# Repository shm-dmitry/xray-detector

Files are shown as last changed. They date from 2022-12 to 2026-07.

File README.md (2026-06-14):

V3 version in progress.
V2 version details:

xray-detector, based on SBT-11A sensor, combined with powerbank futures.

At this moment project finished. Everething works, but with several UI-bugs :)

I will fix them in future, but basically project finished.

Features:
- xray-detector on SBT-11A sensor (senses beta & gamma radiation)
- history in sievert, monthly dose, graph with last severall minutes
- beta-radiation rameasurement feature
- flashlight :-)
- powerbank
- long battery life (about half-year) without recharging
- Simple upgrade firmware - Flushing USB port can be accessed with-out unboxing








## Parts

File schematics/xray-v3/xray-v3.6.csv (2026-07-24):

Reference | Qty | Value | DNP | Exclude from BOM | Exclude from Board | Footprint | Datasheet
BT1 | 1 | LiIon, 3.2 ... 4.2V |  |  |  | Connector_Wire:SolderWire-0.75sqmm_1x02_P7mm_D1.25mm_OD3.5mm
C1 | 1 | 10 pF |  |  |  | Capacitor_SMD:C_0603_1608Metric
C2,C28,C42,C44,C46 | 5 | 22 uF |  |  |  | Capacitor_SMD:C_1210_3225Metric
C3,C57,C59,C60 | 4 | 1 uF |  |  |  | Capacitor_SMD:C_0603_1608Metric
C4,C41 | 2 | 100 uF |  |  |  | Capacitor_Tantalum_SMD:CP_EIA-6032-28_Kemet-C_HandSolder
C5,C13,C30,C32 | 4 | 10 uF |  |  |  | Capacitor_SMD:C_0603_1608Metric
C6 | 1 | 1 nF |  |  |  | Capacitor_SMD:C_0603_1608Metric
C7,C8,C9,C11,C18,C20,C21,C22,C24,C29,C34,C36,C39,C45,C47,C48,C49,C51,C52,C53,C54,C55,C56 | 23 | 100 nF |  |  |  | Capacitor_SMD:C_0603_1608Metric
C10 | 1 | 10 nF * |  |  |  | Capacitor_SMD:C_0603_1608Metric
C12 | 1 | ? * |  |  |  | Capacitor_SMD:C_0603_1608Metric
C14 | 1 | 0.47 uF |  |  |  | Capacitor_SMD:C_0603_1608Metric
C15,C16,C17 | 3 | CBB21, 10 nF, 630V |  |  |  | Capacitor_THT:C_Rect_L13.0mm_W6.5mm_P7.50mm_P10.00mm
C19,C25 | 2 | 4.7 uF |  |  |  | Capacitor_SMD:C_0603_1608Metric
C23,C31 | 2 | 470 pF * |  |  |  | Capacitor_SMD:C_0603_1608Metric
C26,C35,C43 | 3 | 2.2 uF |  |  |  | Capacitor_SMD:C_0603_1608Metric
C27,C33 | 2 | CM-120/S, 120pF, 50V, C0G |  |  |  | Capacitor_THT:C_Disc_D5.0mm_W2.5mm_P2.50mm
C37 | 1 | 47 nF |  |  |  | Capacitor_SMD:C_0603_1608Metric
C38 | 1 | 5 nF |  |  |  | Capacitor_SMD:C_0603_1608Metric
C40 | 1 | 33 pF |  |  |  | Capacitor_SMD:C_0603_1608Metric
C50 | 1 | 2 uF |  |  |  | Capacitor_SMD:C_0603_1608Metric
C58,C61 | 2 | 47 uF |  |  |  | Capacitor_Tantalum_SMD:CP_EIA-3528-21_Kemet-B_HandSolder
D1 | 1 | BZV55C3V0 |  |  |  | Diode_SMD:D_MiniMELF
D2,D10 | 2 | SP0503BAHT |  |  |  | Package_TO_SOT_SMD:SOT-143 | http://www.littelfuse.com/~/media/files/littelfuse/technical%20resources/documents/data%20sheets/sp05xxba.pdf
D3 | 1 | 10BQ060 |  |  |  | Diode_SMD:D_SMB_Handsoldering
D4,D5,D6 | 3 | BYV26C |  |  |  | Diode_THT:D_5W_P10.16mm_Horizontal
D7 | 1 | BAT54A |  |  |  | Package_TO_SOT_SMD:SOT-23 | http://www.diodes.com/_files/datasheets/ds11005.pdf
D8 | 1 | BAT54C |  |  |  | Package_TO_SOT_SMD:SOT-23 | http://www.diodes.com/_files/datasheets/ds11005.pdf
D9,D11 | 2 | BAV21W |  |  |  | Diode_SMD:D_SOD-123 | http://www.vishay.com/docs/85543/bav17.pdf
D12 | 1 | L-2060YD |  |  |  | LED_THT:LED_D1.8mm_W3.3mm_H2.4mm
F1 | 1 | 3A |  |  |  | Library:FuseHolder1808
H1,H2,H3,H4,H5 | 5 | MountingHole |  |  |  | MountingHole:MountingHole_2.2mm_M2
J1 | 1 | TR_SHIELD |  |  |  | Connector_Wire:SolderWirePad_1x01_SMD_2x4mm
J2 | 1 | USB_C_Receptacle_USB2.0_16P |  |  |  | Library:USB_C_P16_MIDMOUNT_1.6 | https://www.usb.org/sites/default/files/documents/usb_type-c.zip
J3 | 1 | SBM20_1_+ |  |  |  | Connector_Wire:SolderWirePad_1x01_SMD_2x4mm
J4 | 1 | SBM20_2_+ |  |  |  | Connector_Wire:SolderWirePad_1x01_SMD_2x4mm
J5 | 1 | SBM20_- |  |  |  | Connector_Wire:SolderWirePad_1x01_SMD_2x4mm
J6 | 1 | SBT9_+ |  |  |  | Connector_Wire:SolderWirePad_1x01_SMD_2x4mm
J7 | 1 | SBT9_- |  |  |  | Connector_Wire:SolderWirePad_1x01_SMD_2x4mm
J8 | 1 | USB_A |  |  |  | Library:USB_A | ~
J9 | 1 | DP/VCC |  |  |  | Connector_JST:JST_XH_B3B-XH-A_1x03_P2.50mm_Vertical
J10 | 1 | DSPI |  |  |  | Connector_JST:JST_XH_B4B-XH-A_1x04_P2.50mm_Vertical
J11 | 1 | DP/DC |  |  |  | Connector_JST:JST_XH_B2B-XH-A_1x02_P2.50mm_Vertical
J12 | 1 | Conn_01x06_Pin |  |  | Исключен из платы
L1 | 1 | 1 uH |  |  |  | Inductor_SMD:L_Bourns_SRP1050WA
Q1 | 1 | IRLML0060TR |  |  |  | Package_TO_SOT_SMD:SOT-23 | https://www.infineon.com/dgdl/irlml0030pbf.pdf?fileId=5546d462533600a401535664773825df
Q2,Q3 | 2 | BC847 |  |  |  | Package_TO_SOT_SMD:SOT-23 | http://www.infineon.com/dgdl/Infineon-BC847SERIES_BC848SERIES_BC849SERIES_BC850SERIES-DS-v01_01-en.pdf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
Q4,Q5,Q6,Q7 | 4 | IRLML5203 |  |  |  | Package_TO_SOT_SMD:SOT-23 | https://www.infineon.com/dgdl/irlml5203pbf.pdf?fileId=5546d462533600a40153566868da261d
R1,R2,R3,R7,R8,R12,R13,R19,R38,R47,R49,R50,R51,R55,R56,R57,R58,R60,R63,R66,R70 | 21 | 10K |  |  |  | Resistor_SMD:R_0805_2012Metric_Pad1.20x1.40mm_HandSolder
R4,R46 | 2 | 2K |  |  |  | Resistor_SMD:R_0805_2012Metric_Pad1.20x1.40mm_HandSolder
R5 | 1 | 0.01 |  |  |  | Resistor_SMD:R_2512_6332Metric
R6 | 1 | 5 |  |  |  | Resistor_SMD:R_0805_2012Metric_Pad1.20x1.40mm_HandSolder
R9 | 1 | 1K |  |  |  | Resistor_SMD:R_0805_2012Metric_Pad1.20x1.40mm_HandSolder
R10,R30,R31,R37,R40,R62 | 6 | 200K |  |  |  | Resistor_SMD:R_0805_2012Metric_Pad1.20x1.40mm_HandSolder
R11,R28,R29 | 3 | 5K1 |  |  |  | Resistor_SMD:R_0805_2012Metric_Pad1.20x1.40mm_HandSolder
R14 | 1 | 1M |  |  |  | Resistor_SMD:R_0805_2012Metric_Pad1.20x1.40mm_HandSolder
R15,R16,R33,R44 | 4 | 100K |  |  |  | Resistor_SMD:R_0805_2012Metric_Pad1.20x1.40mm_HandSolder
R17,R18,R21,R22,R24,R25,R26,R27,R34,R35,R36 | 11 | 2M |  |  | Исключен из платы | Resistor_SMD:R_0805_2012Metric_Pad1.20x1.40mm_HandSolder
R20 | 1 | 540 |  |  |  | Resistor_SMD:R_0805_2012Metric_Pad1.20x1.40mm_HandSolder
R23 | 1 | 1K5 |  |  |  | Resistor_SMD:R_0805_2012Metric_Pad1.20x1.40mm_HandSolder
R32,R41 | 2 | 47K |  |  |  | Resistor_SMD:R_0805_2012Metric_Pad1.20x1.40mm_HandSolder
R39,R64 | 2 | 150K |  |  |  | Resistor_SMD:R_0805_2012Metric_Pad1.20x1.40mm_HandSolder
R42 | 1 | 51K |  |  |  | Resistor_SMD:R_0805_2012Metric_Pad1.20x1.40mm_HandSolder
R43 | 1 | 16K |  |  |  | Resistor_SMD:R_0805_2012Metric_Pad1.20x1.40mm_HandSolder
R45 | 1 | 17.5K |  |  |  | Resistor_SMD:R_0805_2012Metric_Pad1.20x1.40mm_HandSolder
R48 | 1 | 0R025 |  |  |  | Resistor_SMD:R_2512_6332Metric
R52,R53 | 2 | 4K7 |  |  |  | Resistor_SMD:R_0805_2012Metric_Pad1.20x1.40mm_HandSolder
R54 | 1 | 0 |  |  |  | Resistor_SMD:R_0805_2012Metric_Pad1.20x1.40mm_HandSolder
R59 | 1 | 500 |  |  |  | Resistor_SMD:R_0805_2012Metric_Pad1.20x1.40mm_HandSolder
R61 | 1 | 20K |  |  |  | Resistor_SMD:R_0805_2012Metric_Pad1.20x1.40mm_HandSolder
R65 | 1 | 20 |  |  |  | Resistor_SMD:R_0805_2012Metric_Pad1.20x1.40mm_HandSolder
R67,R68,R69 | 3 | 0 * |  |  |  | Resistor_SMD:R_0805_2012Metric_Pad1.20x1.40mm_HandSolder
R71 | 1 | 620 |  |  |  | Resistor_SMD:R_0805_2012Metric_Pad1.20x1.40mm_HandSolder
RV1 | 1 | JBR-3296W-103-R |  |  |  | Potentiometer_THT:Potentiometer_Bourns_3296W_Vertical
SW1 | 1 | SW_SP3T_SH |  |  |  | Library:SK13D07VG4
SW2 | 1 | START |  |  |  | Library:SW_Tactile_SKHH_Angled_SH | https://www.ckswitches.com/media/1482/kms.pdf
SW3 | 1 | RESET |  |  |  | Button_Switch_THT:SW_TH_Tactile_Omron_B3F-107x
TH1 | 1 | NTC, 10K |  |  |  | Connector_Wire:SolderWire-0.25sqmm_1x02_P4.2mm_D0.65mm_OD1.7mm
TP1 | 1 | BS_WKUP |  |  |  | TestPoint:TestPoint_Loop_D2.50mm_Drill1.0mm
TP2 | 1 | BS_INT |  |  |  | TestPoint:TestPoint_Loop_D2.50mm_Drill1.0mm
TP3 | 1 | UV_DISCH |  |  |  | TestPoint:TestPoint_2Pads_Pitch5.08mm_Drill1.3mm
TP4 | 1 | VCCQ |  |  |  | TestPoint:TestPoint_Pad_1.0x1.0mm
TP5 | 1 | SBM20_SGN |  |  |  | TestPoint:TestPoint_Pad_1.0x1.0mm
TP6 | 1 | SBT9_SGN |  |  |  | TestPoint:TestPoint_Pad_1.0x1.0mm
TP7 | 1 | B_WKUP |  |  |  | TestPoint:TestPoint_Pad_1.0x1.0mm
TP8 | 1 | RST_DIV |  |  |  | TestPoint:TestPoint_Pad_1.0x1.0mm
TP9 | 1 | HV_PWM |  |  |  | TestPoint:TestPoint_Loop_D2.50mm_Drill1.0mm
TP10 | 1 | HV_FB |  |  |  | TestPoint:TestPoint_Loop_D2.50mm_Drill1.0mm
TP11 | 1 | TIMER_ON_IMPL |  |  |  | TestPoint:TestPoint_Pad_1.0x1.0mm
TP12 | 1 | RST_CHK |  |  |  | TestPoint:TestPoint_Pad_1.0x1.0mm
TP13 | 1 | RST_ON |  |  |  | TestPoint:TestPoint_Pad_1.0x1.0mm
TP14 | 1 | SBM20_SGN_MK |  |  |  | TestPoint:TestPoint_Loop_D2.50mm_Drill1.0mm
TP15 | 1 | SBT9_SGM_MK |  |  |  | TestPoint:TestPoint_Loop_D2.50mm_Drill1.0mm
TP16 | 1 | RST_SGN |  |  |  | TestPoint:TestPoint_Pad_1.0x1.0mm
TP17 | 1 | GND |  |  |  | TestPoint:TestPoint_THTPad_3.0x3.0mm_Drill1.5mm
TP18 | 1 | MK_WKUP |  |  |  | TestPoint:TestPoint_Pad_1.0x1.0mm
TP19 | 1 | MK_ALARM |  |  |  | TestPoint:TestPoint_Pad_1.0x1.0mm
TP20 | 1 | UART_EN |  |  |  | TestPoint:TestPoint_Pad_1.0x1.0mm
TR1 | 1 |  |  |  |  | Library:transformator_SMD_MICRO_EE0504S | https://ae01.alicdn.com/kf/S0bdd4a446f3545a196faa6f50671a665X.jpg
U1 | 1 | BQ27441DRZR-G1A |  |  |  | Library:Texas_S-PDSO-N12_novia | http://www.ti.com/lit/ds/symlink/bq27441-g1.pdf
U2 | 1 | CP2102N-Axx-xQFN28 |  |  |  | Package_DFN_QFN:QFN-28-1EP_5x5mm_P0.5mm_EP3.35x3.35mm | https://www.silabs.com/documents/public/data-sheets/cp2102n-datasheet.pdf
U3,U4,U5,U8,U9,U10 | 6 | SN74LVC1G126DBVR |  |  |  | Package_TO_SOT_SMD:SOT-23-5 | https://www.ti.com/lit/ds/symlink/sn74lvc1g125.pdf
U6,U7,U22 | 3 | SN74LVC1T45DCK |  |  |  | Package_TO_SOT_SMD:SOT-363_SC-70-6 | http://www.ti.com/lit/ds/symlink/sn74lvc1t45.pdf
U11,U13 | 2 | TPS22965 |  |  |  | Package_SON:WSON-8-1EP_3x2.5mm_P0.5mm_EP1.2x1.5mm_PullBack | https://static.chipdip.ru/lib/486/DOC014486558.pdf
U12 | 1 | BQ24090DGQ |  |  |  | Package_SO:MSOP-10-1EP_3x3mm_P0.5mm_EP1.73x1.98mm | http://www.ti.com/lit/ds/symlink/bq24090.pdf
U14 | 1 | TPS61088 |  |  |  | Library:VQFN_20 | https://static.chipdip.ru/lib2/b/858/DOC080858365.pdf
U15,U16 | 2 | ATtiny1616-M |  |  |  | Package_DFN_QFN:VQFN-20-1EP_3x3mm_P0.4mm_EP1.7x1.7mm | http://ww1.microchip.com/downloads/en/DeviceDoc/ATtiny3216_ATtiny1616-data-sheet-40001997B.pdf
U17 | 1 | INA199A3 |  |  |  | Package_TO_SOT_SMD:SOT-363_SC-70-6 | http://www.ti.com/lit/ds/symlink/ina199.pdf
U18,U20 | 2 | LMV331 |  |  |  | Package_TO_SOT_SMD:SOT-23-5_HandSoldering | http://www.ti.com/lit/ds/symlink/lmv331.pdf
U19 | 1 | RV-3028-C7 |  |  |  | Package_SON:MicroCrystal_C7_SON-8_1.5x3.2mm_P0.9mm | https://www.microcrystal.com/fileadmin/Media/Products/RTC/Datasheet/RV-3028-C7.pdf
U21 | 1 | SN74LVC2T45DCUR |  |  |  | Package_SO:VSSOP-8_2.3x2mm_P0.5mm | http://www.ti.com/lit/ds/symlink/sn74lvc2t45.pdf
U23 | 1 | XC6206P282MR |  |  |  | Package_TO_SOT_SMD:SOT-23-3 | https://www.torexsemi.com/file/xc6206/XC6206.pdf
U24 | 1 | Display_2.2inch_ili9341 |  |  | Исключен из платы | Connector_JST:JST_XH_B9B-XH-A_1x09_P2.50mm_Vertical
V1,V2 | 2 | СБМ-20 |  |  | Исключен из платы | Connector_Wire:SolderWire-0.5sqmm_1x02_P4.8mm_D0.9mm_OD2.3mm
V3 | 1 | СБТ-9 |  |  | Исключен из платы | Connector_Wire:SolderWire-0.5sqmm_1x02_P4.8mm_D0.9mm_OD2.3mm

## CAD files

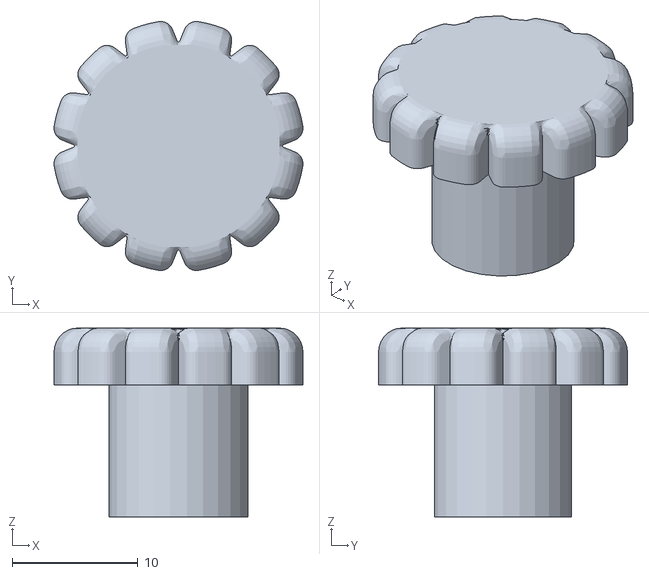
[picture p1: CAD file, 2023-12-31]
3d/box-v2-encoder-cup.stl
19.8 x 19.8 x 15.0

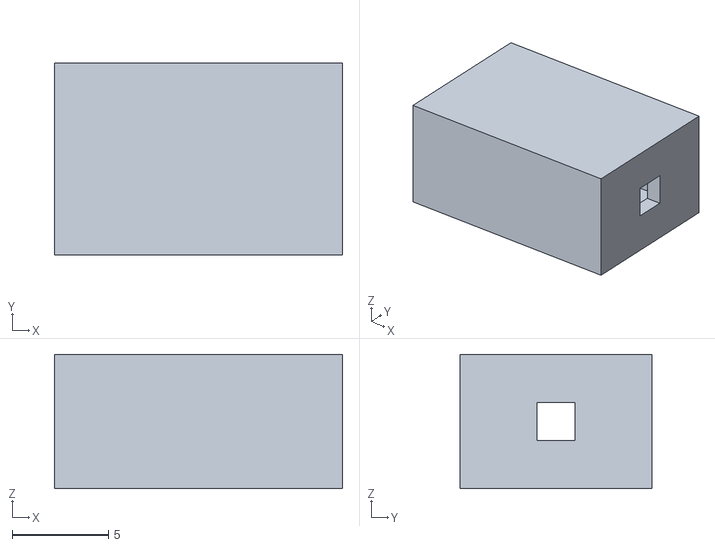
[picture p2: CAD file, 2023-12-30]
3d/box-v2-diode-heat-protection.stl
15.0 x 10.0 x 7.00

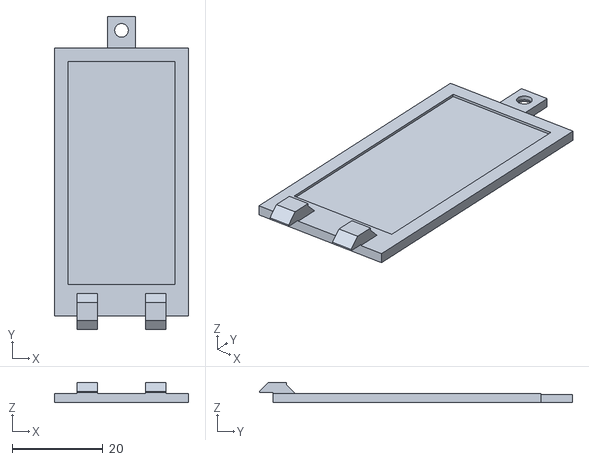
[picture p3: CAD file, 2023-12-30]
3d/box-v2-rad-cap.stl
29.6 x 69.2 x 4.50

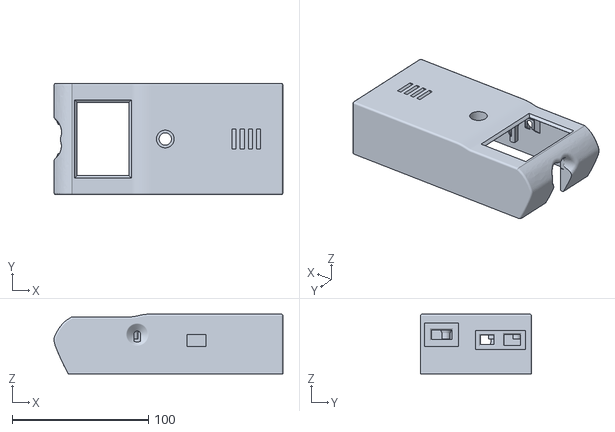
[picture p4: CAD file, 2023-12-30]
3d/box-v2-top.stl
168.1 x 81.8 x 44.0

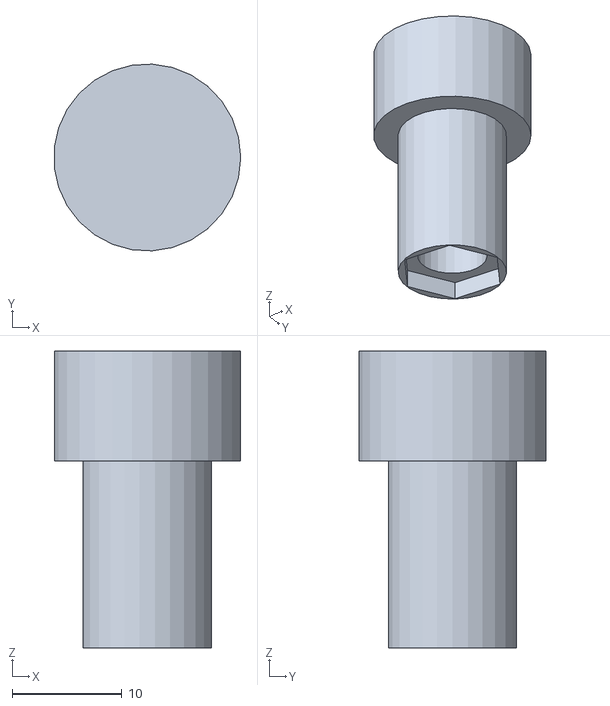
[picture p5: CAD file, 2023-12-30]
3d/box-v2-key.stl
17.0 x 17.0 x 27.0

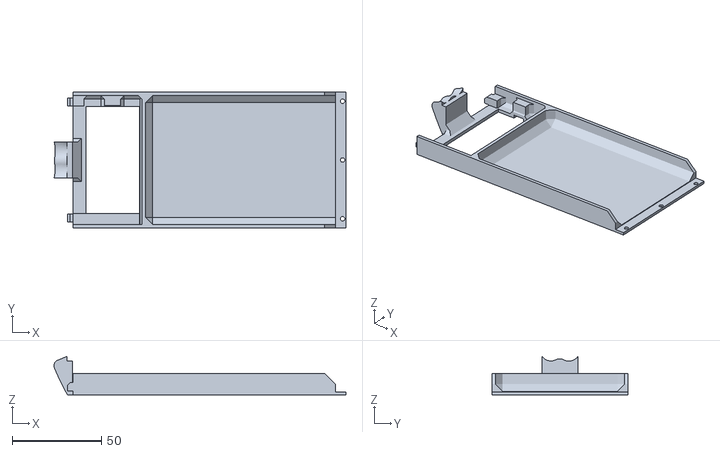
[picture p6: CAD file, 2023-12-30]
3d/box-v2-cup.stl
163.5 x 76.2 x 21.7

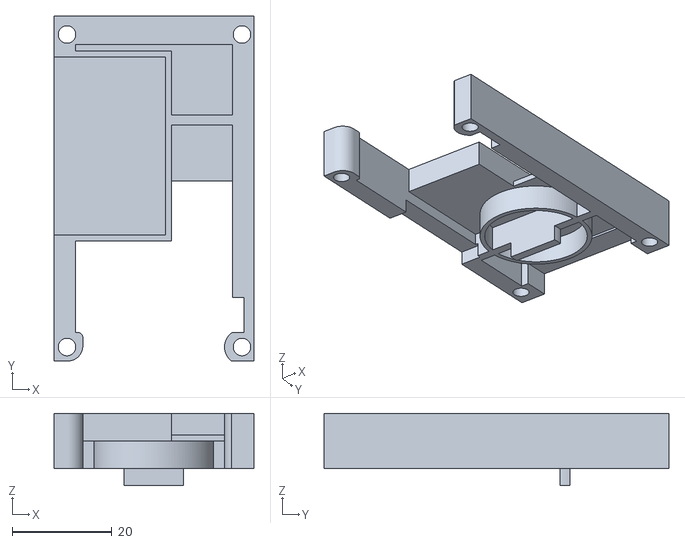
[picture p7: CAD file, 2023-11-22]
3d/box-v2-display-holder.stl
40.0 x 69.0 x 14.5

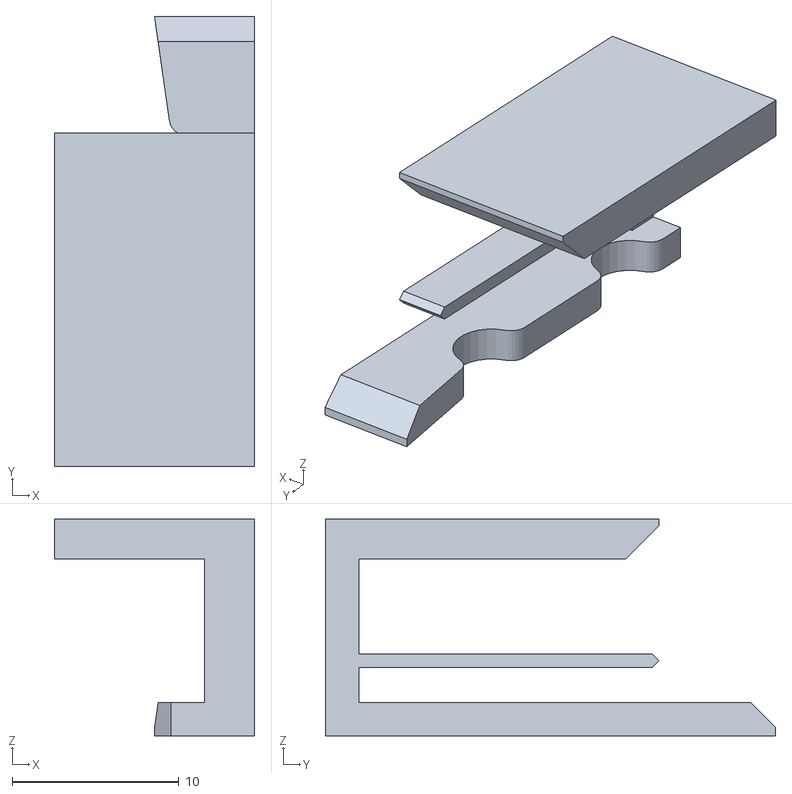
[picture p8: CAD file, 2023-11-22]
3d/box-v2-usb-solder-helper.stl
12.0 x 27.0 x 13.0

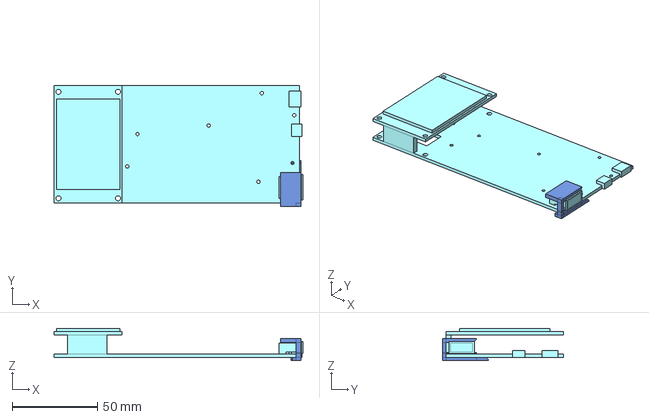
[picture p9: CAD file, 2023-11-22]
3d/box-v2.FCStd
146.2 x 71.0 x 19.0 mm
board
usb-solder-helper

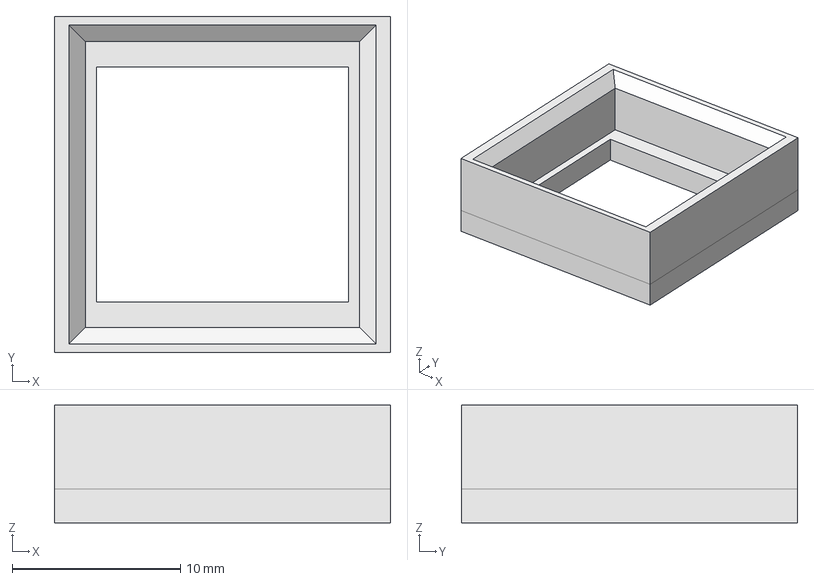
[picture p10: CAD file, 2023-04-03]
3d/transformator-box.FCStd
20.0 x 20.0 x 7.00 mm

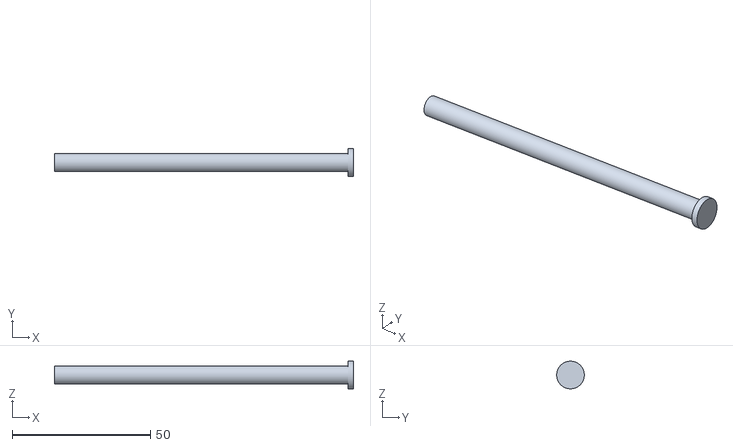
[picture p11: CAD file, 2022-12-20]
3d/transformator-winding-machine-shaft.stl
108.0 x 10.0 x 10.00

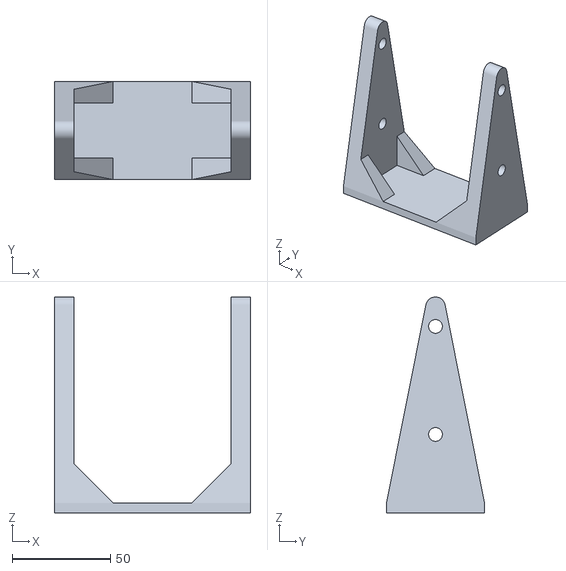
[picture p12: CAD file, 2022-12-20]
3d/transformator-winding-machine-platform.stl
100.0 x 50.0 x 110.0

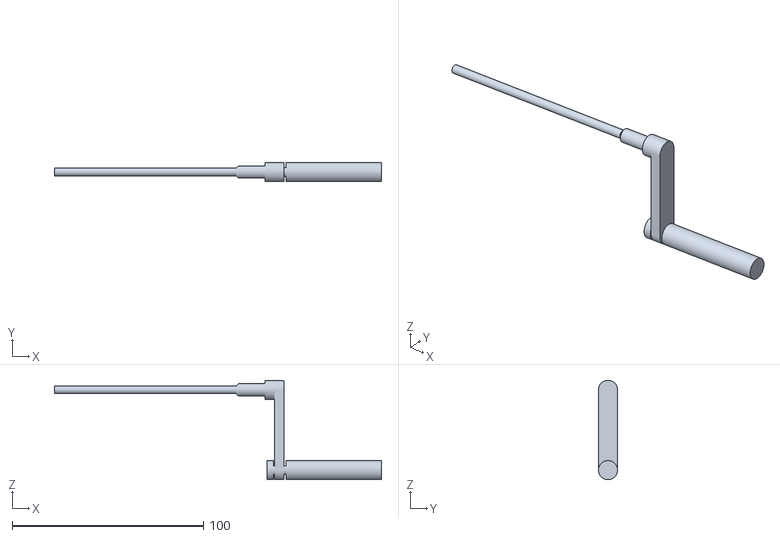
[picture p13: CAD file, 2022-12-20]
3d/transformator-winding-machine-hand.stl
171.0 x 10.0 x 52.0

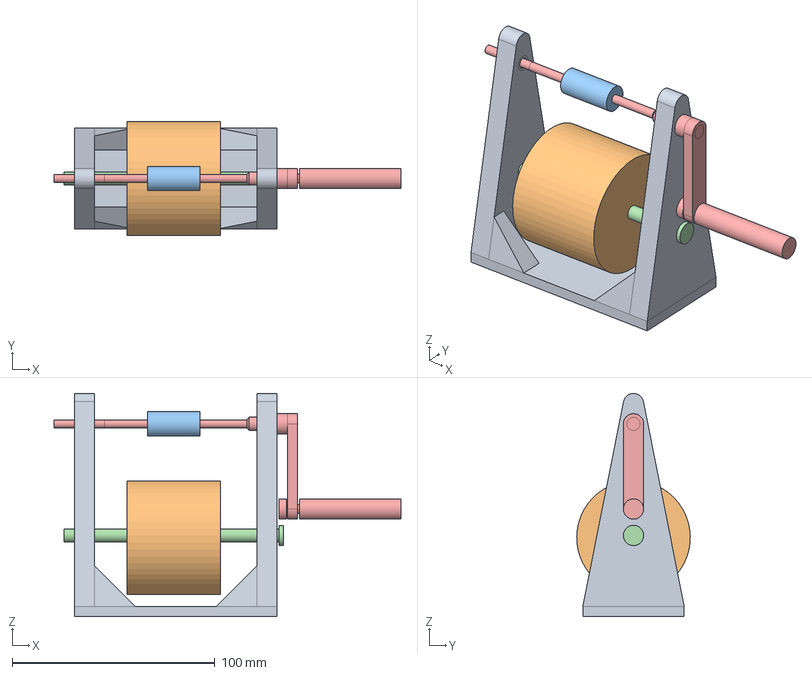
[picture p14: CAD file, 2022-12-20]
3d/transformator-winding-machine.FCStd
171.0 x 56.0 x 110.0 mm
platform
Цилиндр
Цилиндр001
shaft
hand

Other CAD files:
3d/transformator-box.stl

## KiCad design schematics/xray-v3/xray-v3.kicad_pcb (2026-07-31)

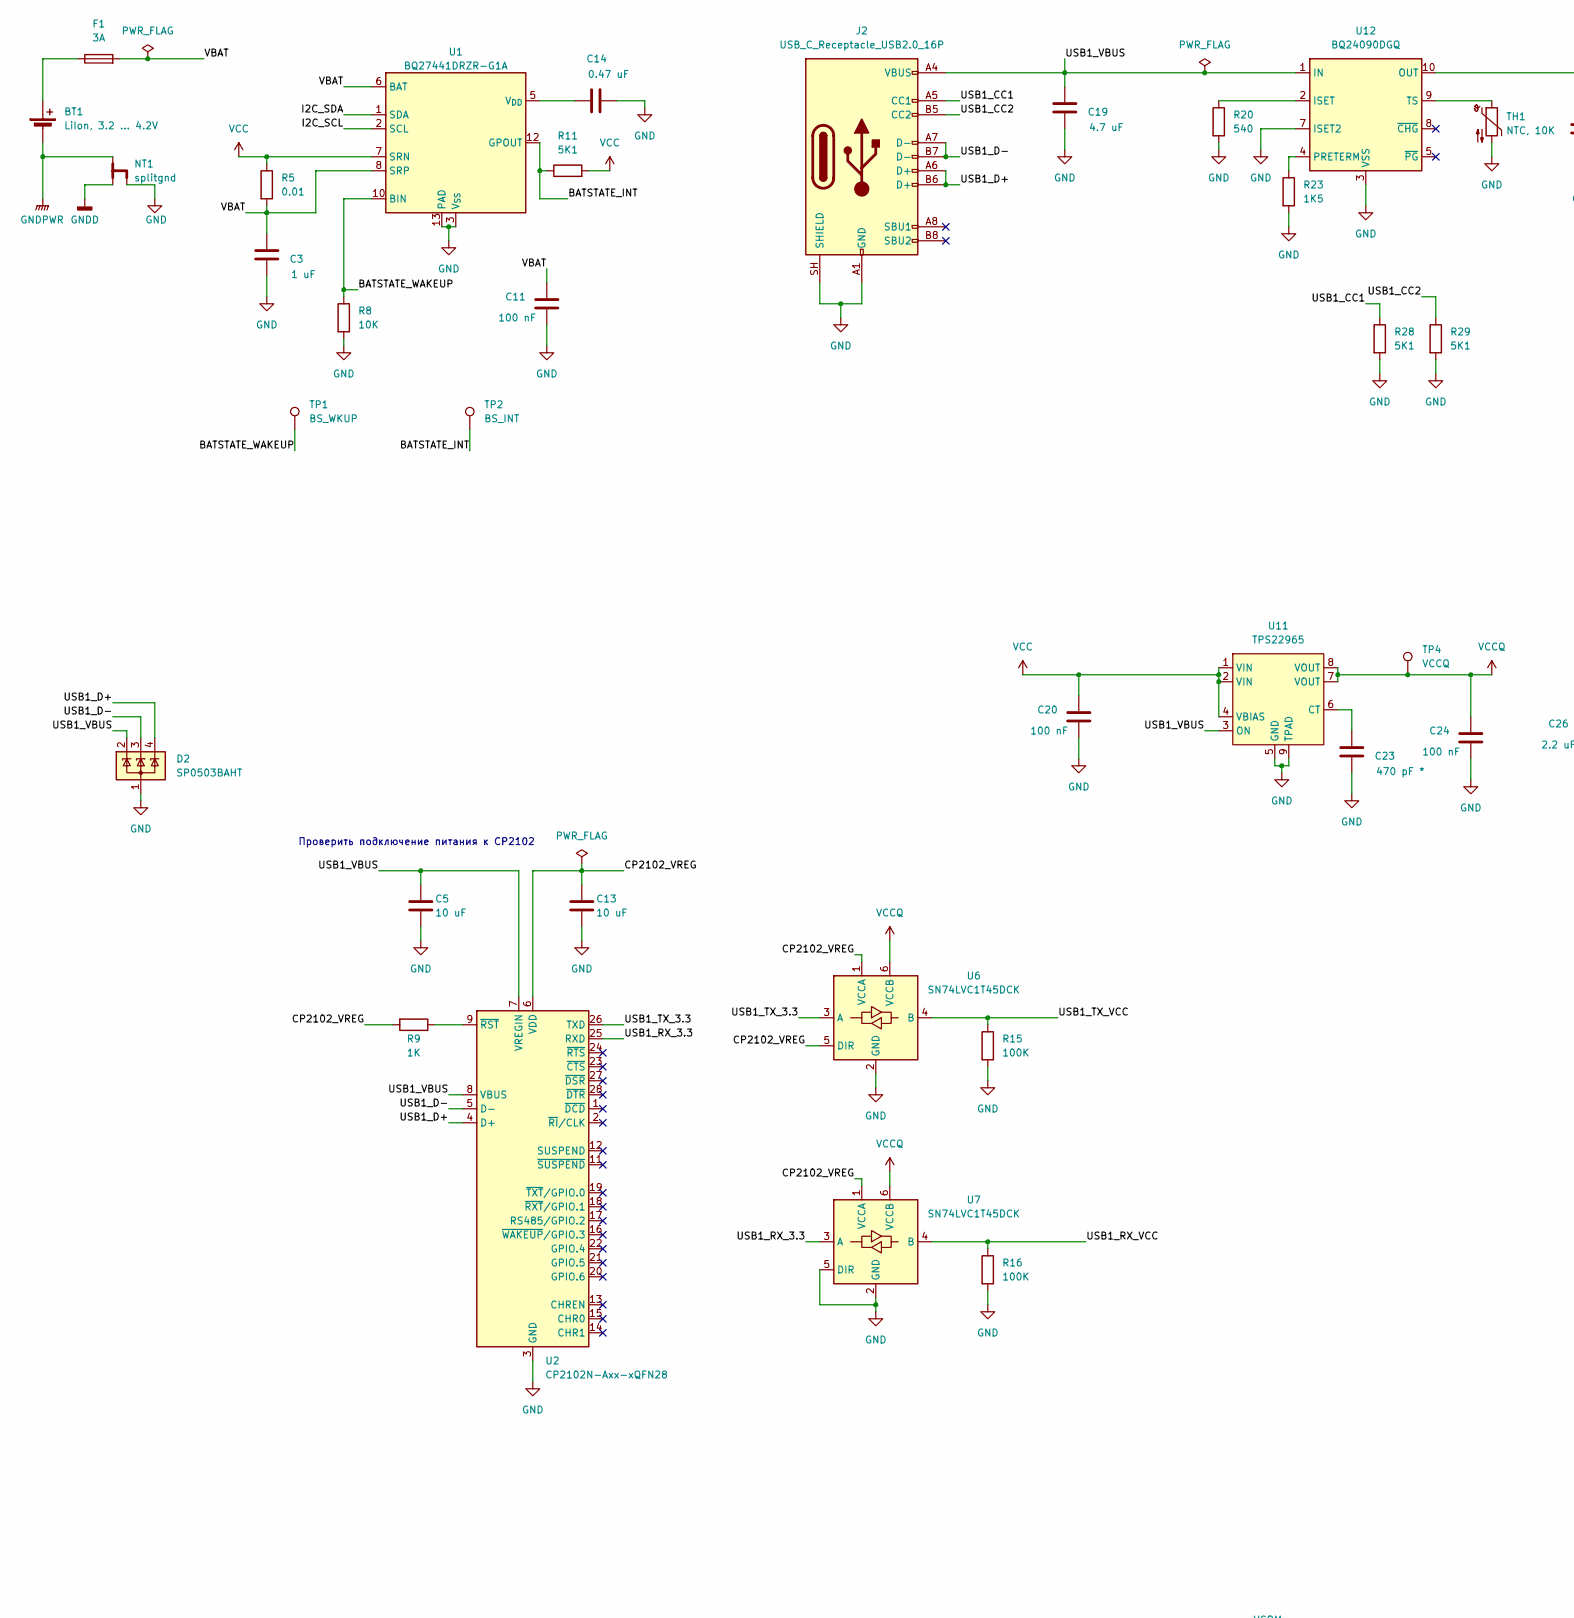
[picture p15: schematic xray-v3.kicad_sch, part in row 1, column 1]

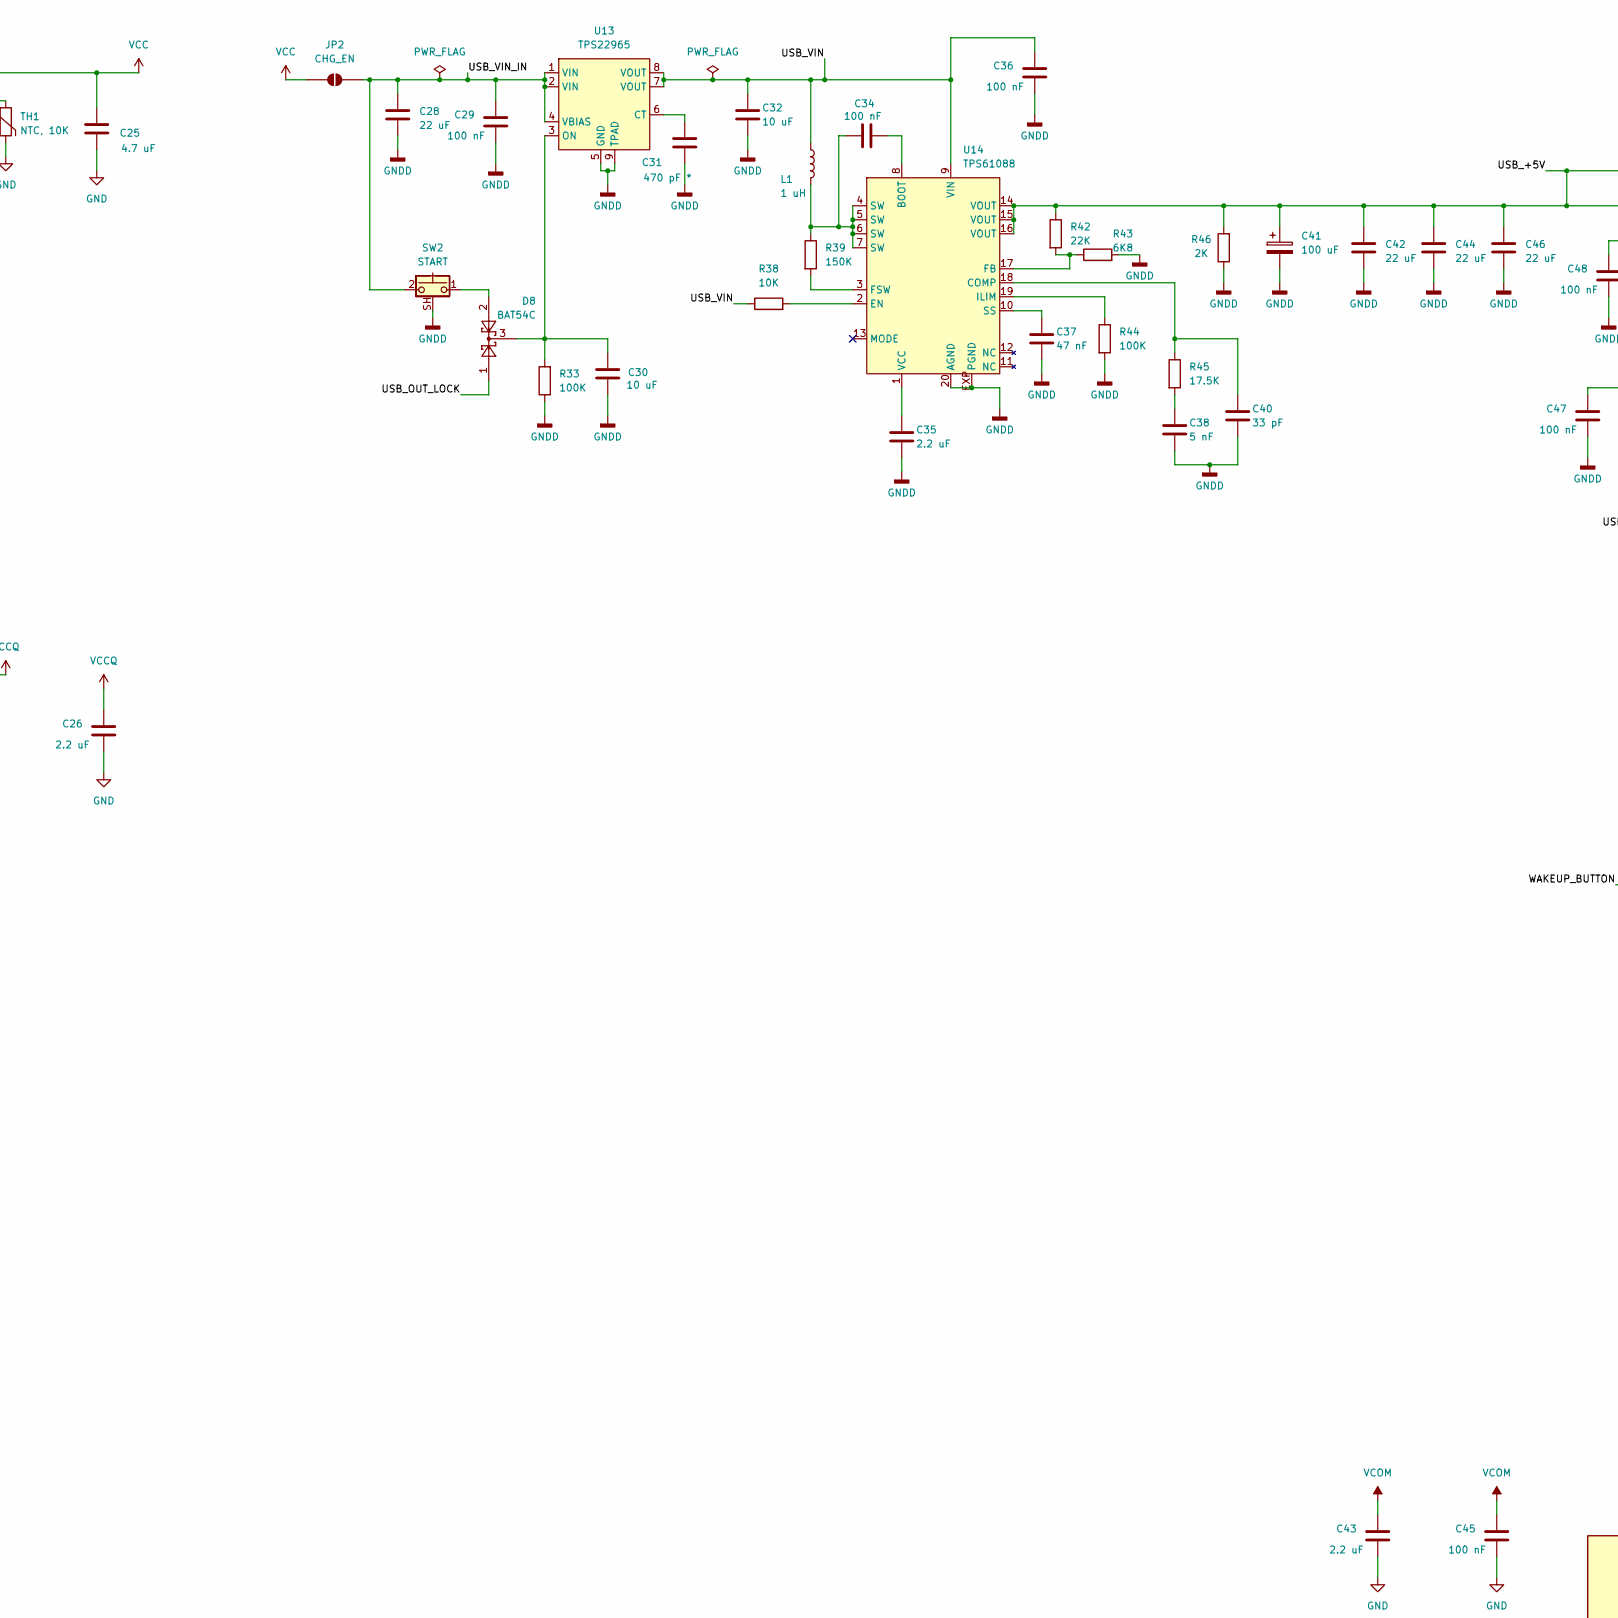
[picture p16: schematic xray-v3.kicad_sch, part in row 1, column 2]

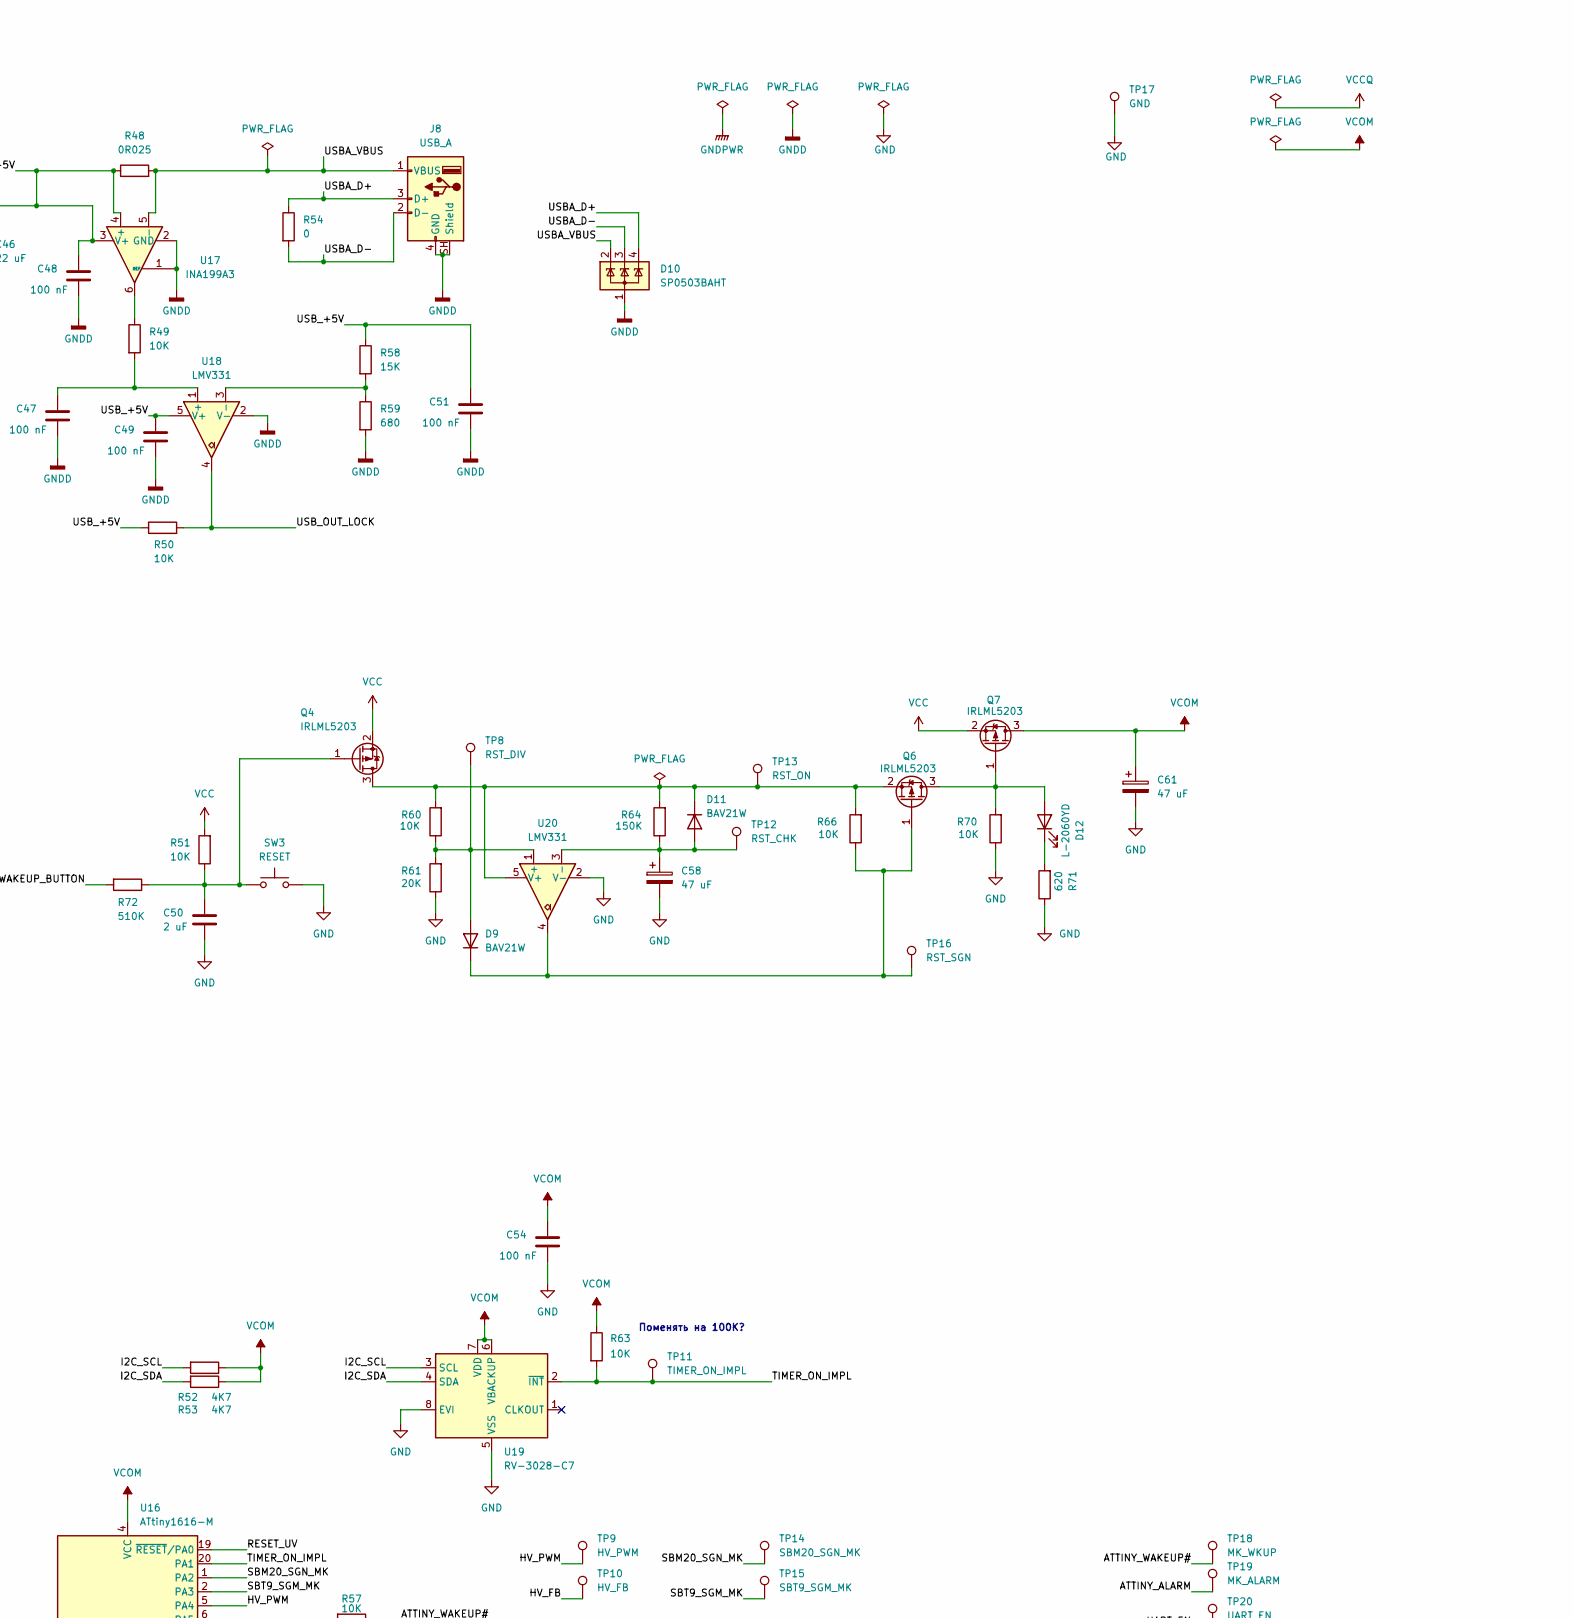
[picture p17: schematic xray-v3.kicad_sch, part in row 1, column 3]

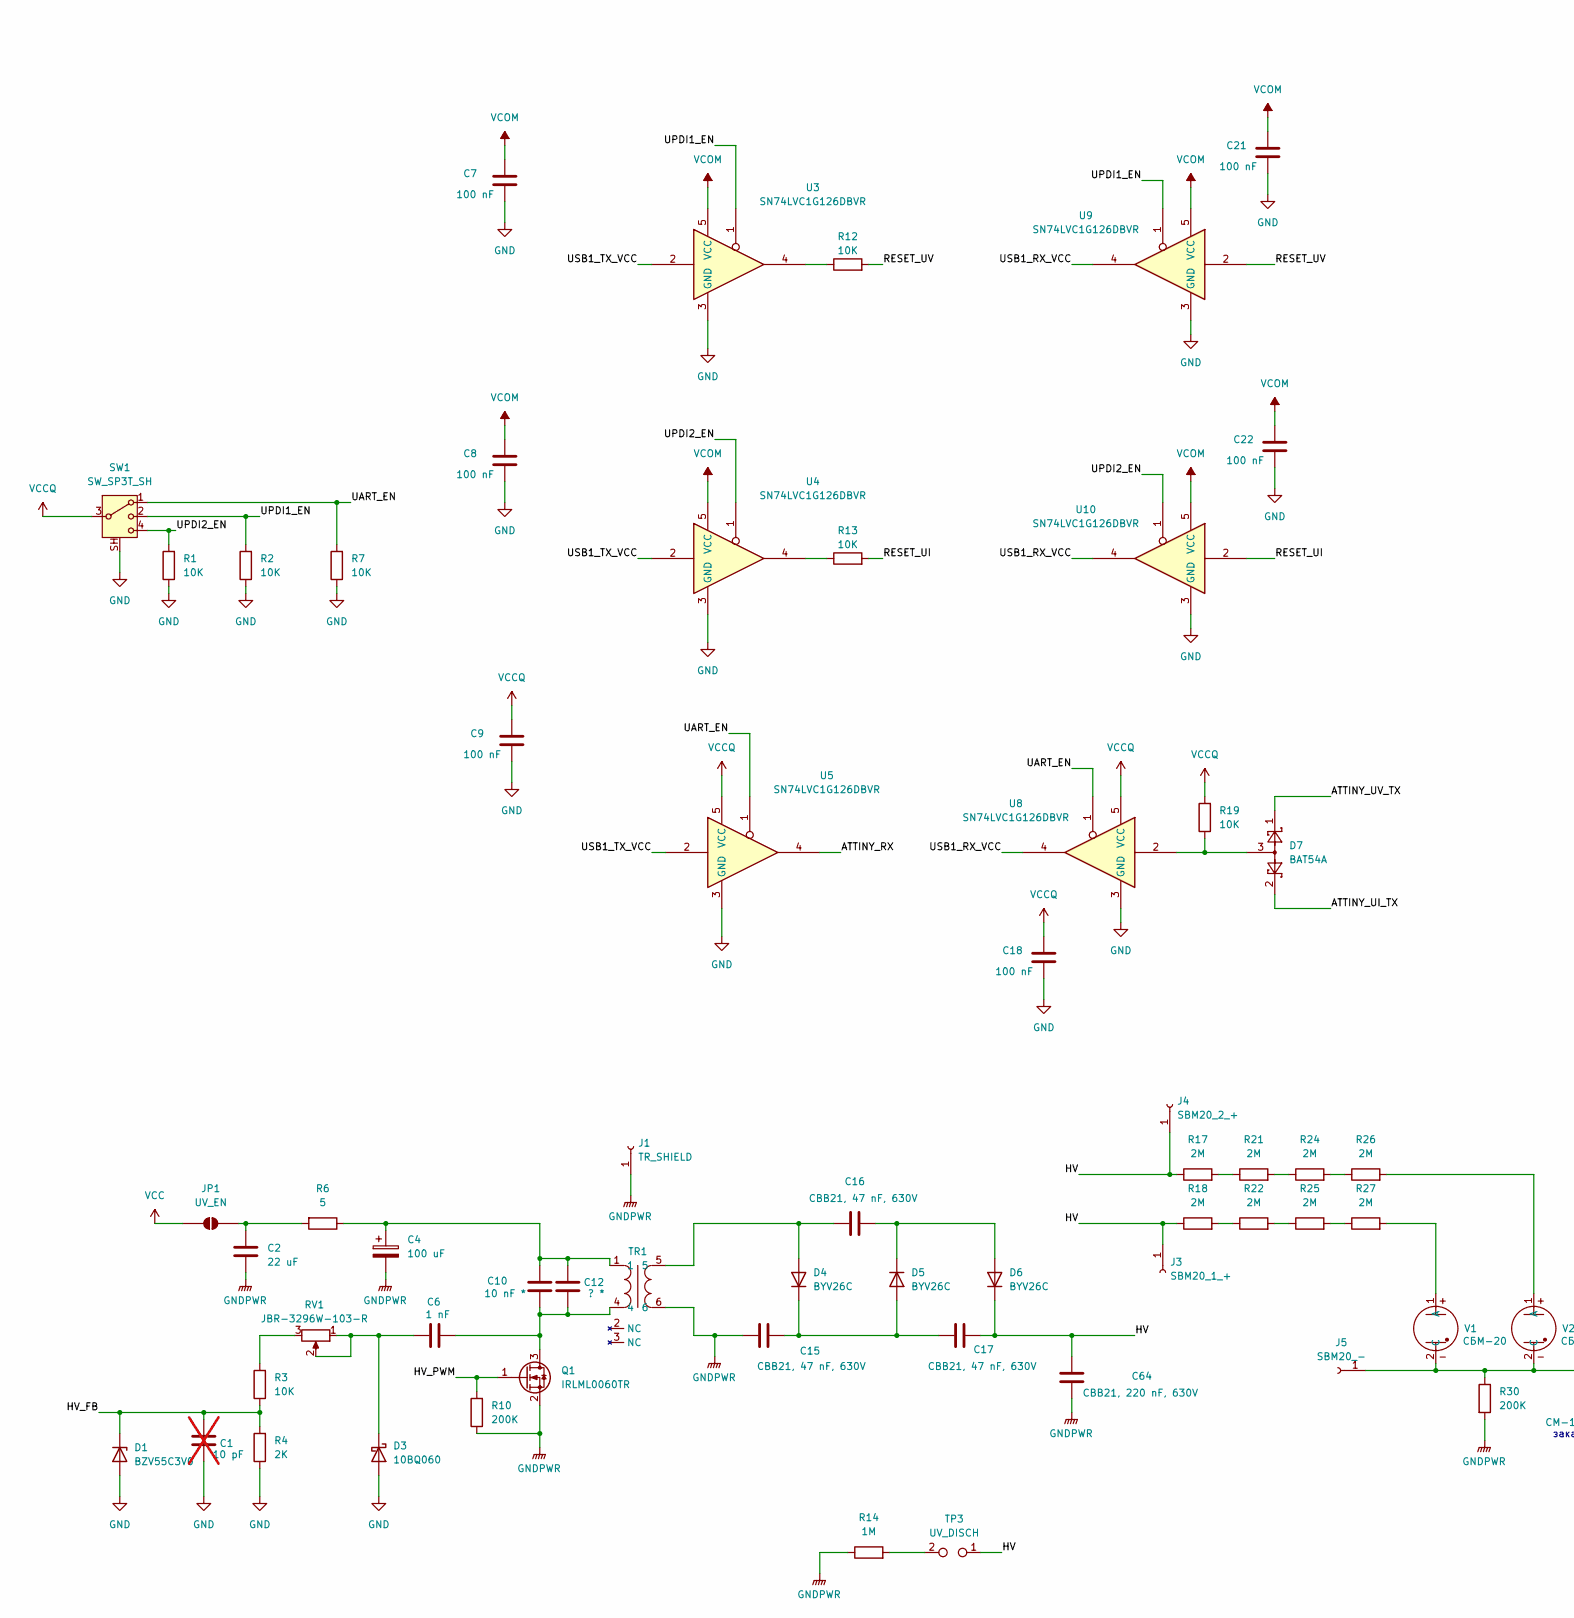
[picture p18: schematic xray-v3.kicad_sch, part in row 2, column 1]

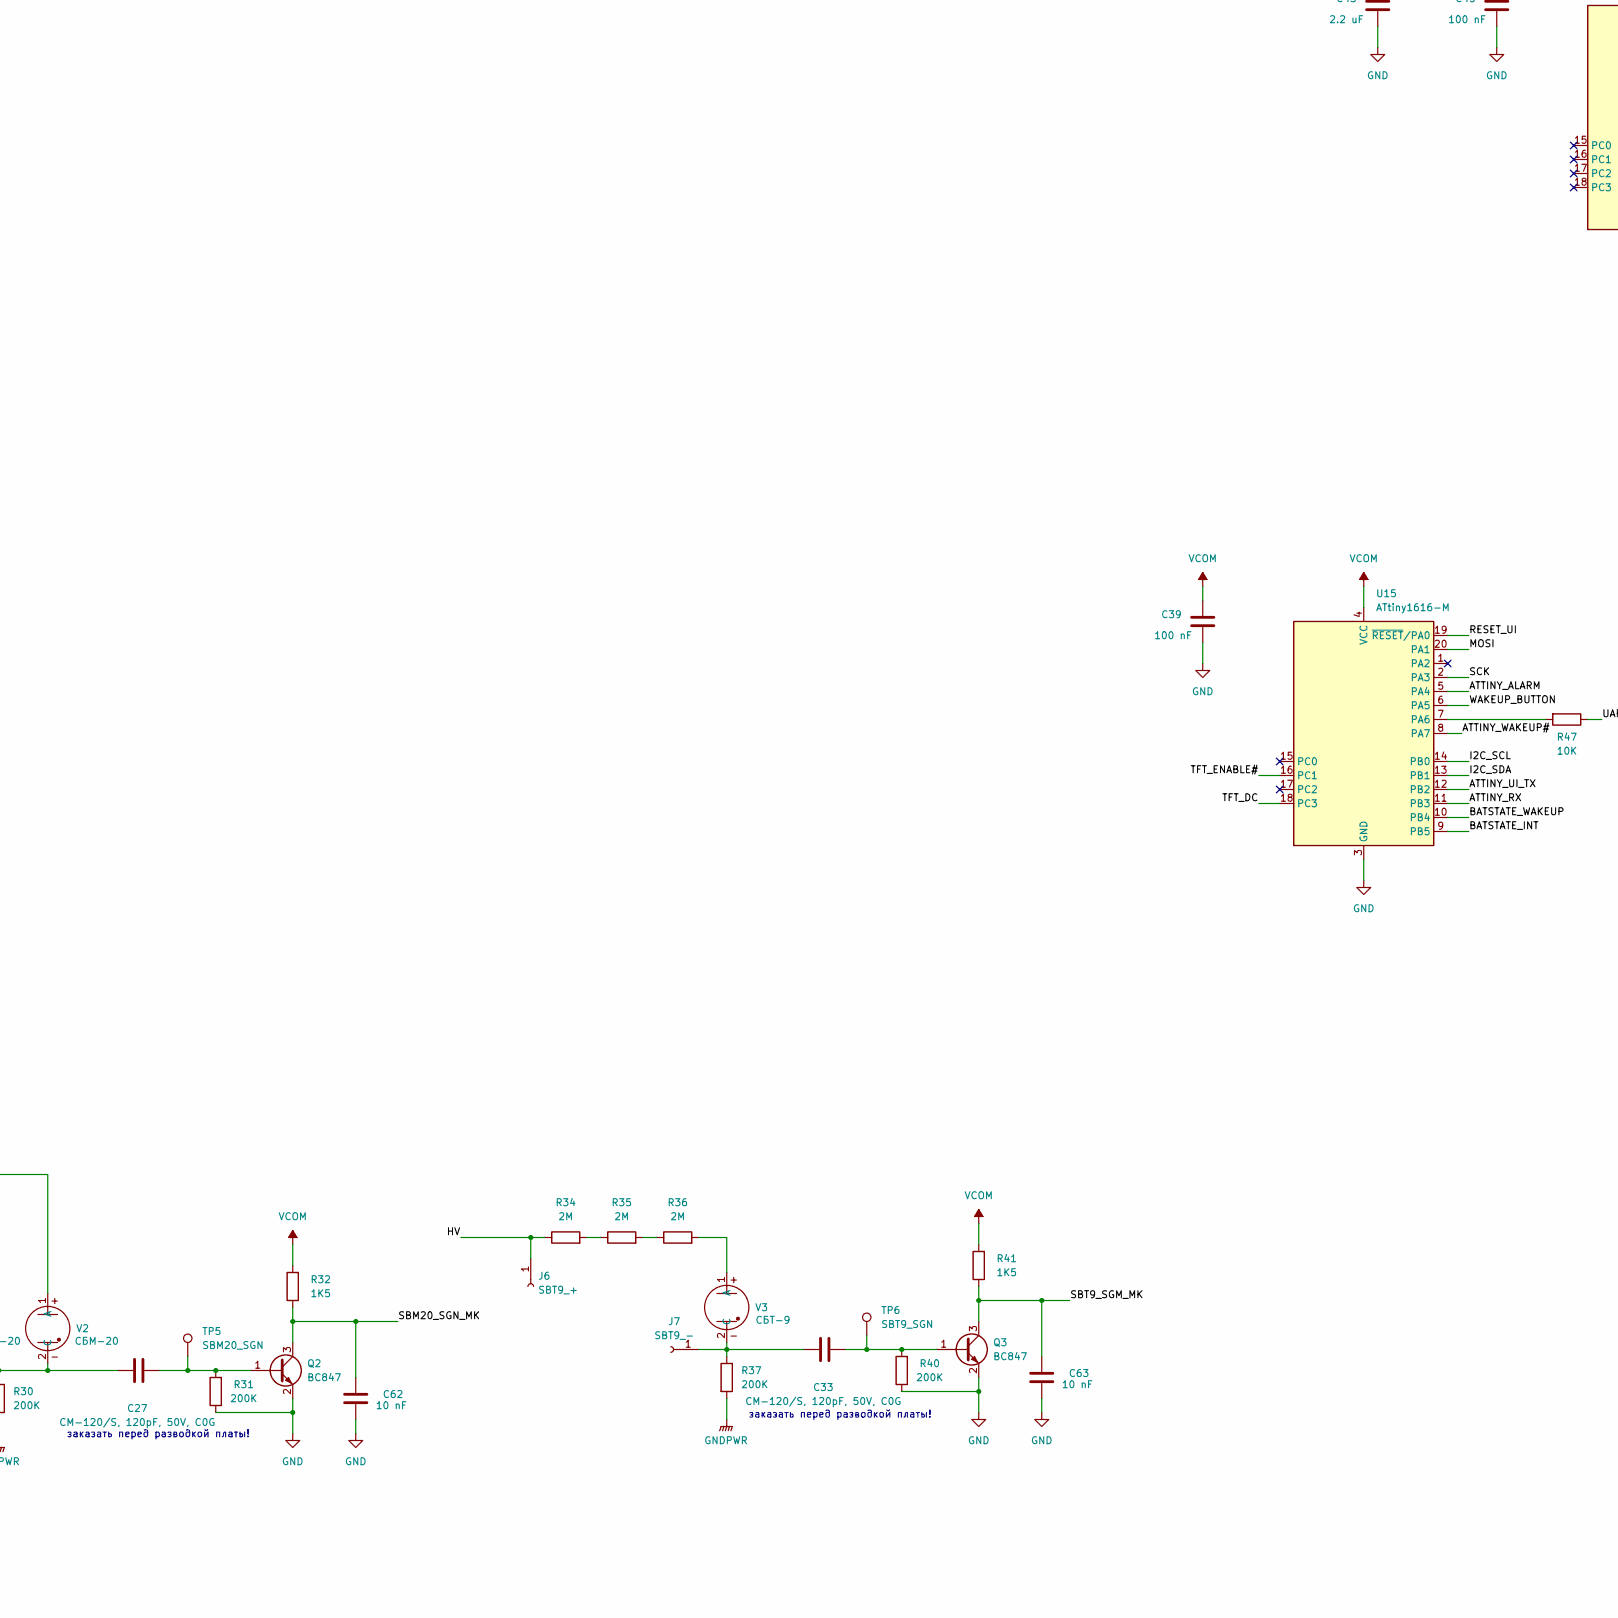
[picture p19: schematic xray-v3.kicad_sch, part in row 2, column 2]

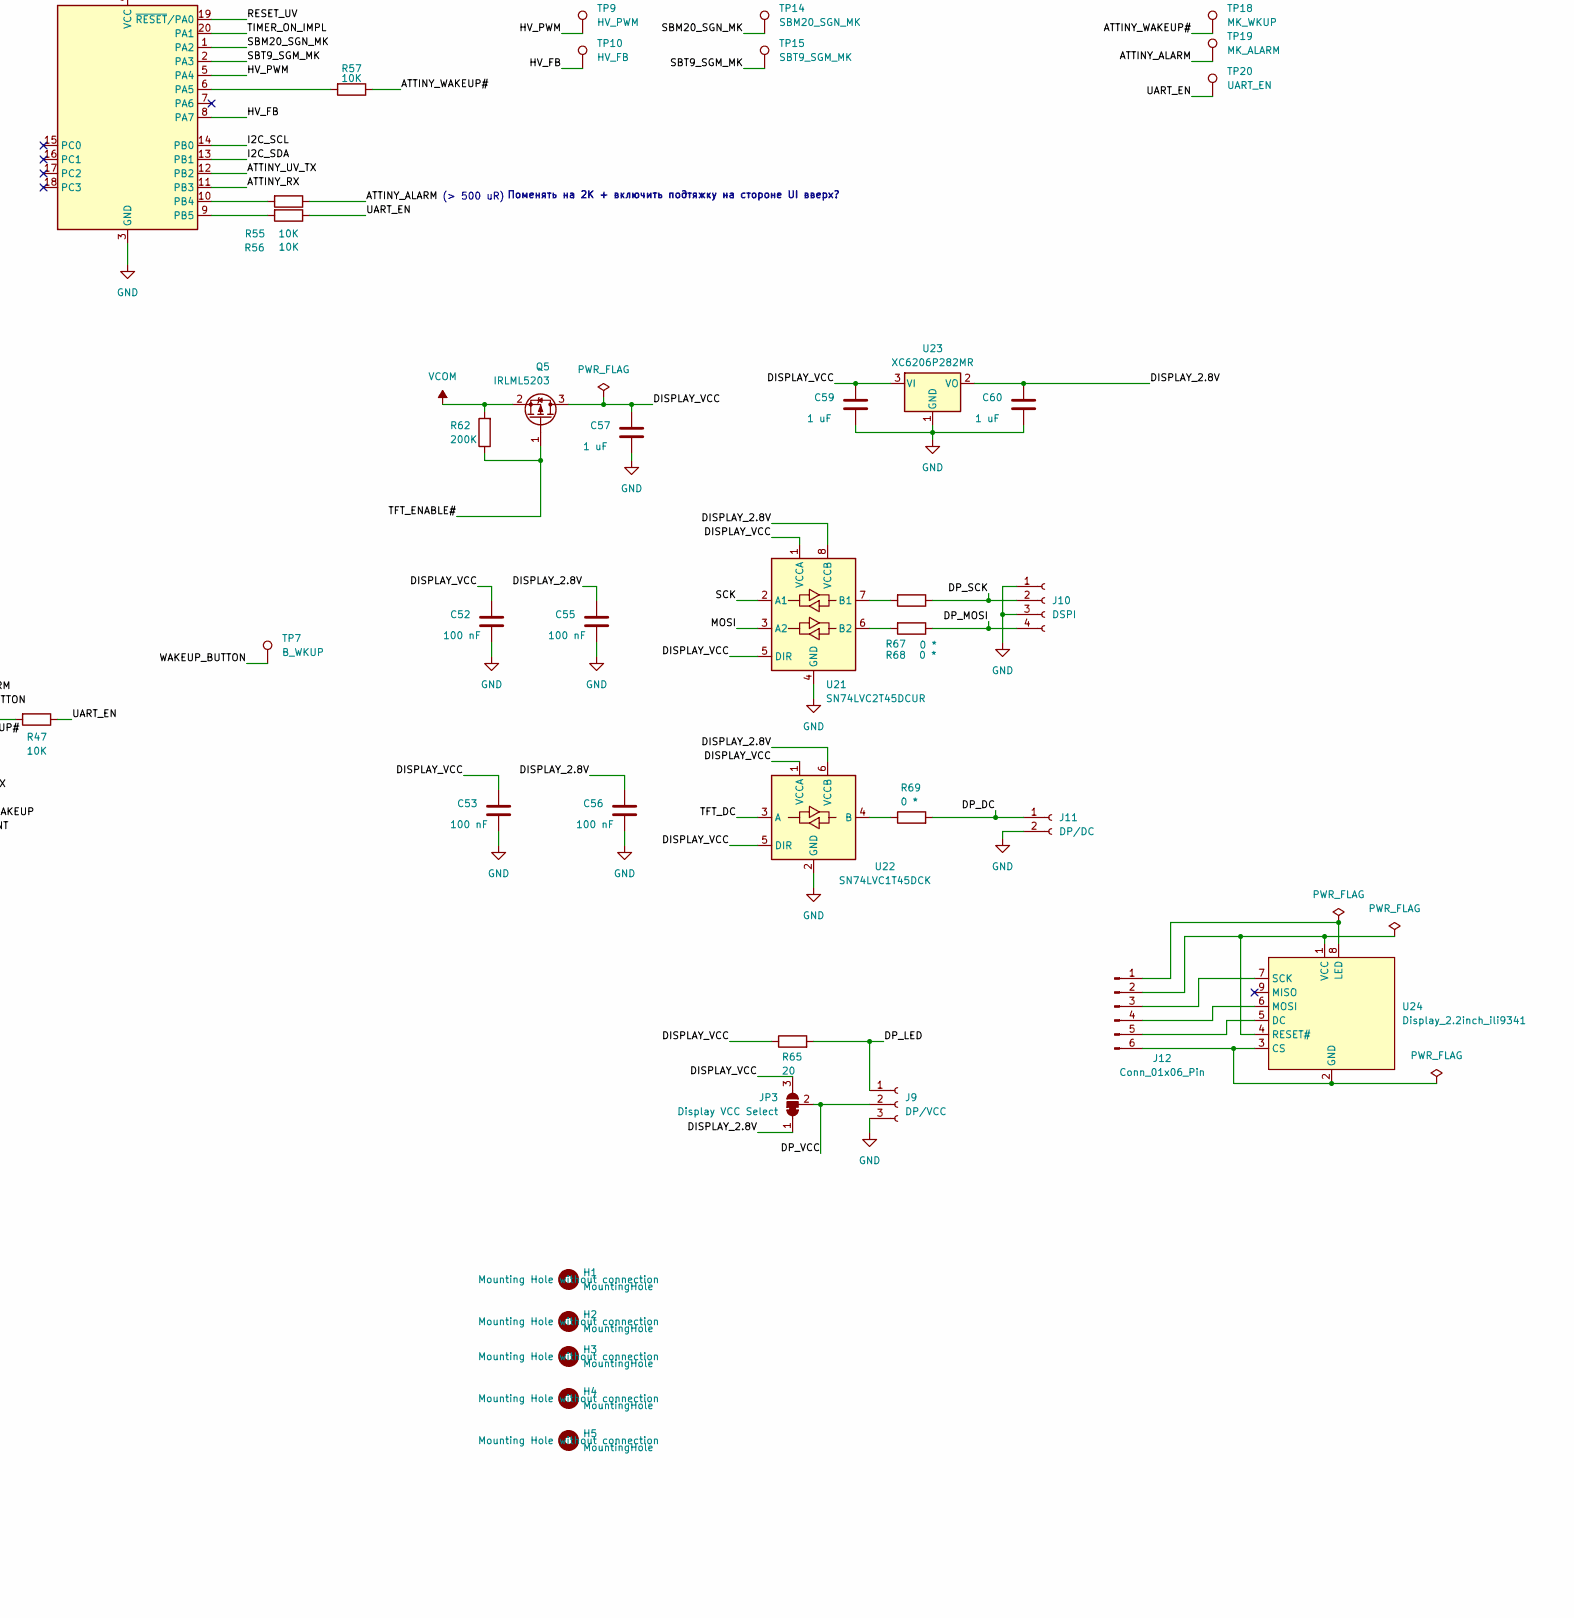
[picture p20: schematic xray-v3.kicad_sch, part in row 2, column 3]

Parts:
BT1: LiIon, 3.2 ... 4.2V; SolderWire-0.75sqmm_1x02_P7mm_D1.25mm_OD3.5mm
C1: 10 pF; C_0603_1608Metric; not fitted
C2, C28, C42, C44, C46: 22 uF; C_1210_3225Metric
C3, C57, C59, C60: 1 uF; C_0603_1608Metric
C4, C41: 100 uF; CP_EIA-6032-28_Kemet-C_HandSolder
C5, C13, C30, C32: 10 uF; C_0603_1608Metric
C6: 1 nF; C_0603_1608Metric
C7, C8, C9, C11, C18, C20, C21, C22, C24, C29, C34, C36, C39, C45, C47, C48, C49, C51, C52, C53, C54, C55, C56: 100 nF; C_0603_1608Metric
C10: 10 nF *; C_0603_1608Metric
C12: ? *; C_0603_1608Metric
C14: 0.47 uF; C_0603_1608Metric
C15, C16, C17: CBB21, 47 nF, 630V; C_Rect_L13.0mm_W6.5mm_P7.50mm_P10.00mm
C19, C25: 4.7 uF; C_0603_1608Metric
C23, C31: 470 pF *; C_0603_1608Metric
C26, C35, C43: 2.2 uF; C_0603_1608Metric
C27, C33: CM-120/S, 120pF, 50V, C0G; C_Disc_D5.0mm_W2.5mm_P2.50mm
C37: 47 nF; C_0603_1608Metric
C38: 5 nF; C_0603_1608Metric
C40: 33 pF; C_0603_1608Metric
C50: 2 uF; C_0603_1608Metric
C58, C61: 47 uF; CP_EIA-3528-21_Kemet-B_HandSolder
C62, C63: 10 nF; C_0603_1608Metric
C64: CBB21, 220 nF, 630V; C_Rect_L13.0mm_W6.5mm_P7.50mm_P10.00mm
D1: BZV55C3V0; D_MiniMELF
D2, D10: SP0503BAHT; SOT-143
D3: 10BQ060; D_SMB_Handsoldering
D4, D5, D6: BYV26C; D_5W_P10.16mm_Horizontal
D7: BAT54A; SOT-23
D8: BAT54C; SOT-23
D9, D11: BAV21W; D_SOD-123
D12: L-2060YD; LED_D1.8mm_W3.3mm_H2.4mm
F1: 3A; FuseHolder1808
H1, H2, H3, H4, H5: MountingHole; MountingHole_2.2mm_M2
J1: TR_SHIELD; SolderWirePad_1x01_SMD_2x4mm
J2: USB_C_Receptacle_USB2.0_16P; USB_C_P16_MIDMOUNT_1.6
J3: SBM20_1_+; SolderWirePad_1x01_SMD_2x4mm
J4: SBM20_2_+; SolderWirePad_1x01_SMD_2x4mm
J5: SBM20_-; SolderWirePad_1x01_SMD_2x4mm
J6: SBT9_+; SolderWirePad_1x01_SMD_2x4mm
J7: SBT9_-; SolderWirePad_1x01_SMD_2x4mm
J8: USB_A
J9: DP/VCC; JST_XH_B3B-XH-A_1x03_P2.50mm_Vertical
J10: DSPI; JST_XH_B4B-XH-A_1x04_P2.50mm_Vertical
J11: DP/DC; JST_XH_B2B-XH-A_1x02_P2.50mm_Vertical
J12: Conn_01x06_Pin
JP1: UV_EN; SolderedJumper-2P-2mm
JP2: CHG_EN; SolderedJumper-2P-2mm
JP3: Display VCC Select; SolderJumper-3_P1.3mm_Bridged12_RoundedPad1.0x1.5mm_NumberL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
L1: 1 uH; L_Bourns_SRP1050WA
NT1: splitgnd; NetTie-3_SMD_Pad2.0mm
Q1: IRLML0060TR; SOT-23
Q2, Q3: BC847; SOT-23
Q4, Q5, Q6, Q7: IRLML5203; SOT-23
R1, R2, R3, R7, R8, R12, R13, R19, R38, R47, R49, R50, R51, R55, R56, R57, R60, R63, R66, R70: 10K; R_0805_2012Metric_Pad1.20x1.40mm_HandSolder
R4, R46: 2K; R_0805_2012Metric_Pad1.20x1.40mm_HandSolder
R5: 0.01; R_2512_6332Metric
R6: 5; R_0805_2012Metric_Pad1.20x1.40mm_HandSolder
R9: 1K; R_0805_2012Metric_Pad1.20x1.40mm_HandSolder
R10, R30, R31, R37, R40, R62: 200K; R_0805_2012Metric_Pad1.20x1.40mm_HandSolder
R11, R28, R29: 5K1; R_0805_2012Metric_Pad1.20x1.40mm_HandSolder
R14: 1M; R_0805_2012Metric_Pad1.20x1.40mm_HandSolder
R15, R16, R33, R44: 100K; R_0805_2012Metric_Pad1.20x1.40mm_HandSolder
R17, R18, R21, R22, R24, R25, R26, R27, R34, R35, R36: 2M; R_0805_2012Metric_Pad1.20x1.40mm_HandSolder
R20: 540; R_0805_2012Metric_Pad1.20x1.40mm_HandSolder
R23, R32, R41: 1K5; R_0805_2012Metric_Pad1.20x1.40mm_HandSolder
R39, R64: 150K; R_0805_2012Metric_Pad1.20x1.40mm_HandSolder
R42: 22K; R_0805_2012Metric_Pad1.20x1.40mm_HandSolder
R43: 6K8; R_0805_2012Metric_Pad1.20x1.40mm_HandSolder
R45: 17.5K; R_0805_2012Metric_Pad1.20x1.40mm_HandSolder
R48: 0R025; R_2512_6332Metric
R52, R53: 4K7; R_0805_2012Metric_Pad1.20x1.40mm_HandSolder
R54: 0; R_0805_2012Metric_Pad1.20x1.40mm_HandSolder
R58: 15K; R_0805_2012Metric_Pad1.20x1.40mm_HandSolder
R59: 680; R_0805_2012Metric_Pad1.20x1.40mm_HandSolder
R61: 20K; R_0805_2012Metric_Pad1.20x1.40mm_HandSolder
R65: 20; R_0805_2012Metric_Pad1.20x1.40mm_HandSolder
R67, R68, R69: 0 *; R_0805_2012Metric_Pad1.20x1.40mm_HandSolder
R71: 620; R_0805_2012Metric_Pad1.20x1.40mm_HandSolder
R72: 510K; R_0805_2012Metric_Pad1.20x1.40mm_HandSolder
RV1: JBR-3296W-103-R; Potentiometer_Bourns_3296W_Vertical
SW1: SW_SP3T_SH; SK13D07VG4
SW2: START; SW_Tactile_SKHH_Angled_SH
SW3: RESET; SW_TH_Tactile_Omron_B3F-107x
TH1: NTC, 10K; SolderWire-0.25sqmm_1x02_P4.2mm_D0.65mm_OD1.7mm
TP1: BS_WKUP; TestPoint_Loop_D2.50mm_Drill1.0mm
TP2: BS_INT; TestPoint_Loop_D2.50mm_Drill1.0mm
TP3: UV_DISCH; TestPoint_2Pads_Pitch5.08mm_Drill1.3mm
TP4: VCCQ; TestPoint_Pad_1.0x1.0mm
TP5: SBM20_SGN; TestPoint_Pad_1.0x1.0mm
TP6: SBT9_SGN; TestPoint_Pad_1.0x1.0mm
TP7: B_WKUP; TestPoint_Pad_1.0x1.0mm
TP8: RST_DIV; TestPoint_Pad_1.0x1.0mm
TP9: HV_PWM; TestPoint_Loop_D2.50mm_Drill1.0mm
TP10: HV_FB; TestPoint_Loop_D2.50mm_Drill1.0mm
TP11: TIMER_ON_IMPL; TestPoint_Pad_1.0x1.0mm
TP12: RST_CHK; TestPoint_Pad_1.0x1.0mm
TP13: RST_ON; TestPoint_Pad_1.0x1.0mm
TP14: SBM20_SGN_MK; TestPoint_Loop_D2.50mm_Drill1.0mm
TP15: SBT9_SGM_MK; TestPoint_Loop_D2.50mm_Drill1.0mm
TP16: RST_SGN; TestPoint_Pad_1.0x1.0mm
TP17: GND; TestPoint_THTPad_3.0x3.0mm_Drill1.5mm
TP18: MK_WKUP; TestPoint_Pad_1.0x1.0mm
TP19: MK_ALARM; TestPoint_Pad_1.0x1.0mm
TP20: UART_EN; TestPoint_Pad_1.0x1.0mm
TR1: transformator_SMD_MICRO_EE0504S
U1: BQ27441DRZR-G1A; Texas_S-PDSO-N12_novia
U2: CP2102N-Axx-xQFN28; QFN-28-1EP_5x5mm_P0.5mm_EP3.35x3.35mm
U3, U4, U5, U8, U9, U10: SN74LVC1G126DBVR; SOT-23-5
U6, U7, U22: SN74LVC1T45DCK; SOT-363_SC-70-6
U11, U13: TPS22965; WSON-8-1EP_3x2.5mm_P0.5mm_EP1.2x1.5mm_PullBack
U12: BQ24090DGQ; MSOP-10-1EP_3x3mm_P0.5mm_EP1.73x1.98mm
U14: TPS61088; VQFN_20
U15, U16: ATtiny1616-M; VQFN-20-1EP_3x3mm_P0.4mm_EP1.7x1.7mm
U17: INA199A3; SOT-363_SC-70-6
U18, U20: LMV331; SOT-23-5_HandSoldering
U19: RV-3028-C7; MicroCrystal_C7_SON-8_1.5x3.2mm_P0.9mm
U21: SN74LVC2T45DCUR; VSSOP-8_2.3x2mm_P0.5mm
U23: XC6206P282MR; SOT-23-3
U24: Display_2.2inch_ili9341; JST_XH_B9B-XH-A_1x09_P2.50mm_Vertical
V1, V2: СБМ-20; SolderWire-0.5sqmm_1x02_P4.8mm_D0.9mm_OD2.3mm
V3: СБТ-9; SolderWire-0.5sqmm_1x02_P4.8mm_D0.9mm_OD2.3mm

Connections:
/ATTINY_ALARM: R55.1, TP19.1 (1_1), U15.5 (PA4)
/ATTINY_RX: U5.4, U15.11 (PB3), U16.11 (PB3)
/ATTINY_UI_TX: D7.2, U15.12 (PB2)
/ATTINY_UV_TX: D7.1, U16.12 (PB2)
/ATTINY_WAKEUP#: R57.1, TP18.1 (1_1), U15.8 (PA7)
/BATSTATE_INT: R11.1, TP2.1 (1_1), U1.12 (GPOUT), U15.9 (PB5)
/BATSTATE_WAKEUP: R8.1, TP1.1 (1_1), U1.10 (BIN), U15.10 (PB4)
/CP2102_VREG: C13.1, R9.2, U2.6 (VDD), U6.1 (VCCA), U6.5 (DIR), U7.1 (VCCA)
/DISPLAY_2.8V: C55.1, C56.1, C60.1, JP3.1 (A), U21.8 (VCCB), U22.6 (VCCB), U23.2 (VO)
/DISPLAY_VCC: C52.1, C53.1, C57.1, C59.1, JP3.3 (B), Q5.3 (D), R65.1, U21.1 (VCCA), U21.5 (DIR), U22.1 (VCCA), U22.5 (DIR), U23.3 (VI)
/DP_DC: J11.1, R69.2
/DP_LED: J9.1, R65.2
/DP_MOSI: J10.4, R68.1
/DP_SCK: J10.2, R67.1
/DP_VCC: J9.2, JP3.2 (C)
/HV: C17.2, C64.2, D6.1 (K), J3.1 (Pin_1_1), J4.1 (Pin_1_1), J6.1 (Pin_1_1), R17.1, R18.1, R34.1, TP3.1
/HV_FB: C1.1, D1.1 (K), R3.1, R4.2, TP10.1 (1_1), U16.8 (PA7)
/HV_PWM: Q1.1 (G), R10.2, TP9.1 (1_1), U16.5 (PA4)
/I2C_SCL: R52.2, U1.2 (SCL), U15.14 (PB0), U16.14 (PB0), U19.3 (SCL)
/I2C_SDA: R53.2, U1.1 (SDA), U15.13 (PB1), U16.13 (PB1), U19.4 (SDA)
/MOSI: U15.20 (PA1), U21.3 (A2)
/RESET_UI: R13.2, U10.2, U15.19 (~RESET/PA0)
/RESET_UV: R12.2, U9.2, U16.19 (~RESET/PA0)
/SBM20_SGN_MK: C62.1, Q2.3 (C), R32.1, TP14.1 (1_1), U16.1 (PA2)
/SBT9_SGM_MK: C63.1, Q3.3 (C), R41.1, TP15.1 (1_1), U16.2 (PA3)
/SCK: U15.2 (PA3), U21.2 (A1)
/TFT_DC: U15.18 (PC3), U22.3 (A)
/TFT_ENABLE#: Q5.1 (G), R62.1, U15.16 (PC1)
/TIMER_ON_IMPL: R63.2, TP11.1 (1_1), U16.20 (PA1), U19.2 (~INT)
/UART_EN: R7.2, R47.1, R56.1, SW1.1, TP20.1 (1_1), U5.1, U8.1
/UPDI1_EN: R2.2, SW1.2, U3.1, U9.1
/UPDI2_EN: R1.2, SW1.4, U4.1, U10.1
/USB1_CC1: J2.A5 (CC1), R28.1
/USB1_CC2: J2.B5 (CC2), R29.1
/USB1_D+: D2.4 (K), J2.A6 (D+), J2.B6 (D+), U2.4 (D+)
/USB1_D-: D2.3 (K), J2.A7 (D-), J2.B7 (D-), U2.5 (D-)
/USB1_RX_3.3: U2.25 (RXD), U7.3 (A)
/USB1_RX_VCC: R16.1, U7.4 (B), U8.4, U9.4, U10.4
/USB1_TX_3.3: U2.26 (TXD), U6.3 (A)
/USB1_TX_VCC: R15.1, U3.2, U4.2, U5.2, U6.4 (B)
/USB1_VBUS: C5.1, C19.1, D2.2 (K), J2.A4 (VBUS), J2.A9 (VBUS), J2.B4 (VBUS), J2.B9 (VBUS), U2.7 (VREGIN), U2.8 (VBUS), U11.3 (ON), U12.1 (IN)
/USBA_D+: D10.4 (K), J8.3 (D+), R54.1
/USBA_D-: D10.3 (K), J8.2 (D-), R54.2
/USBA_VBUS: D10.2 (K), J8.1 (VBUS), R48.2, U17.5 (-)
/USB_+5V: C41.1, C42.1, C44.1, C46.1, C48.1, C49.1, C51.1, R42.1, R46.2, R48.1, R50.1, R58.1, U14.14 (VOUT), U14.15 (VOUT), U14.16 (VOUT), U17.3 (V+), U17.4 (+), U18.5 (V+)
/USB_OUT_LOCK: D8.1, R50.2, U18.4
/USB_VIN: C32.1, C36.1, L1.1, R38.1, U13.7 (VOUT), U13.8 (VOUT), U14.9 (VIN)
/USB_VIN_IN: C28.1, C29.1, JP2.2 (B), SW2.2, U13.1 (VIN), U13.2 (VIN), U13.4 (VBIAS)
/VBAT: C3.1, C11.1, F1.2, R5.2, U1.6 (BAT), U1.8 (SRP)
/WAKEUP_BUTTON: R72.2, TP7.1 (1_1), U15.6 (PA5)
GND: C1.2, C3.2, C5.2, C7.2, C8.2, C9.2, C11.2, C13.2, C14.2, C18.2, C19.2, C20.2, C21.2, C22.2, C23.2, C24.2, C25.2, C26.2, C39.2, C43.2, C45.2, C50.1, C52.2, C53.2, C54.2, C55.2, C56.2, C57.2, C58.2, C59.2, C60.2, C61.2, C62.2, C63.2, D1.2 (A), D2.1 (A), D3.2 (A), J2.A1 (GND), J2.A12 (GND), J2.B1 (GND), J2.B12 (GND), J2.SH (SHIELD), J9.3, J10.1, J10.3, J11.2, NT1.3, Q2.2 (E), Q3.2 (E), R1.1, R2.1, R4.1, R7.1, R8.2, R15.2, R16.2, R20.2, R23.2, R28.2, R29.2, R31.1, R40.1, R61.1, R70.1, R71.1, SW1.SH, SW3.1, TH1.2, TP17.1 (1_1), U1.3 (V_{SS}), U1.13 (PAD), U2.3 (GND), U2.29 (GND), U3.3 (GND), U4.3 (GND), U5.3 (GND), U6.2 (GND), U7.2 (GND), U7.5 (DIR), U8.3 (GND), U9.3 (GND), U10.3 (GND), U11.5 (GND), U11.9 (TPAD), U12.3 (VSS), U12.7 (ISET2), U12.11 (VSS), U15.3 (GND), U15.21 (GND), U16.3 (GND), U16.21 (GND), U19.5 (VSS), U19.8 (EVI), U20.2 (V-), U21.4 (GND), U22.2 (GND), U23.1 (GND)
GNDD: C28.2, C29.2, C30.2, C31.2, C32.2, C35.2, C36.2, C37.2, C38.2, C40.2, C41.2, C42.2, C44.2, C46.2, C47.2, C48.2, C49.2, C51.2, D10.1 (A), J8.4 (GND), J8.SH (Shield), NT1.1, R33.1, R43.2, R44.2, R46.1, R59.2, SW2.SH (B), U13.5 (GND), U13.9 (TPAD), U14.20 (AGND), U14.EXP (PGND), U17.1 (REF), U17.2 (GND), U18.2 (V-)
GNDPWR: BT1.2 (-), C2.2, C4.2, C15.1, C64.1, J1.1 (Pin_1_1), NT1.2, Q1.2 (S), R10.1, R14.1, R30.2, R37.2, TR1.6
unnamed: BT1.1 (+), F1.1
unnamed: C4.1, C10.2, C12.2, R6.1, TR1.1
unnamed: C34.2, L1.2, R39.1, U14.4 (SW), U14.5 (SW), U14.6 (SW), U14.7 (SW)
unnamed: C38.1, R45.2
unnamed: C6.2, D3.1 (K), RV1.1, RV1.2
unnamed: C16.1, D4.2 (A), TR1.5
unnamed: C15.2, C17.1, D4.1 (K), D5.2 (A)
unnamed: C16.2, D5.1 (K), D6.2 (A)
unnamed: D7.3, R19.1, U8.2
unnamed: D8.2, SW2.1
unnamed: D9.2 (A), R60.1, R61.2, TP8.1 (1_1), U20.1 (+)
unnamed: D9.1 (K), Q6.1 (G), R66.1, TP16.1 (1_1), U20.4
unnamed: C58.1, D11.2 (A), R64.1, TP12.1 (1_1), U20.3 (-)
unnamed: D11.1 (K), Q4.3 (D), Q6.2 (S), R60.2, R64.2, R66.2, TP13.1 (1_1), U20.5 (V+)
unnamed: D12.2 (A), Q6.3 (D), Q7.1 (G), R70.2
unnamed: D12.1 (K), R71.2
unnamed: C27.1, J5.1 (Pin_1_1), R30.1, V1.2 (C), V2.2 (C)
unnamed: C33.1, J7.1 (Pin_1_1), R37.1, V3.2 (C)
unnamed: J12.1, U24.8 (LED)
unnamed: J12.2, U24.1 (VCC), U24.4 (RESET#)
unnamed: J12.3, U24.7 (SCK)
unnamed: J12.4, U24.6 (MOSI)
unnamed: J12.5, U24.5 (DC)
unnamed: J12.6, U24.2 (GND), U24.3 (CS)
unnamed: C2.1, JP1.2 (B), R6.2
unnamed: C6.1, C10.1, C12.1, Q1.3 (D), TR1.4
unnamed: C27.2, Q2.1 (B), R31.2, TP5.1 (1_1)
unnamed: C33.2, Q3.1 (B), R40.2, TP6.1 (1_1)
unnamed: C50.2, Q4.1 (G), R51.1, R72.1, SW3.2
unnamed: R3.2, RV1.3
unnamed: R12.1, U3.4
unnamed: R13.1, U4.4
unnamed: R14.2, TP3.2
unnamed: R17.2, R21.1
unnamed: R18.2, R22.1
unnamed: R21.2, R24.1
unnamed: R22.2, R25.1
unnamed: R24.2, R26.1
unnamed: R25.2, R27.1
unnamed: R26.2, V2.1 (A)
unnamed: R27.2, V1.1 (A)
unnamed: R34.2, R35.1
unnamed: R35.2, R36.1
unnamed: R36.2, V3.1 (A)
unnamed: R49.1, U17.6
unnamed: C14.1, U1.5 (V_{DD})
unnamed: R9.1, U2.9 (~RST)
unnamed: C23.1, U11.6 (CT)
unnamed: R20.1, U12.2 (ISET)
unnamed: R23.1, U12.4 (PRETERM)
unnamed: TH1.1, U12.9 (TS)
unnamed: C31.1, U13.6 (CT)
unnamed: C30.1, D8.3, R33.2, U13.3 (ON)
unnamed: C34.1, U14.8 (BOOT)
unnamed: C40.1, R45.1, U14.18 (COMP)
unnamed: R38.2, U14.2 (EN)
unnamed: R42.2, R43.1, U14.17 (FB)
unnamed: R39.2, U14.3 (FSW)
unnamed: R44.1, U14.19 (ILIM)
unnamed: C37.1, U14.10 (SS)
unnamed: C35.1, U14.1 (VCC)
unnamed: R47.2, U15.7 (PA6)
unnamed: R57.2, U16.6 (PA5)
unnamed: R55.2, U16.10 (PB4)
unnamed: R56.2, U16.9 (PB5)
unnamed: C47.1, R49.2, U18.1 (+)
unnamed: R58.2, R59.1, U18.3 (-)
unnamed: R67.2, U21.7 (B1)
unnamed: R68.2, U21.6 (B2)
unnamed: R69.1, U22.4 (B)
VCC: C20.1, C25.1, JP1.1 (A), JP2.1 (A), Q4.2 (S), Q7.2 (S), R5.1, R11.2, R51.2, U1.7 (SRN), U11.1 (VIN), U11.2 (VIN), U11.4 (VBIAS), U12.10 (OUT)
VCCQ: C9.1, C18.1, C24.1, C26.1, R19.2, SW1.3, TP4.1 (1_1), U5.5 (VCC), U6.6 (VCCB), U7.6 (VCCB), U8.5 (VCC), U11.7 (VOUT), U11.8 (VOUT)
VCOM: C7.1, C8.1, C21.1, C22.1, C39.1, C43.1, C45.1, C54.1, C61.1, Q5.2 (S), Q7.3 (D), R32.2, R41.2, R52.1, R53.1, R62.2, R63.1, U3.5 (VCC), U4.5 (VCC), U9.5 (VCC), U10.5 (VCC), U15.4 (VCC), U16.4 (VCC), U19.6 (VBACKUP), U19.7 (VDD)

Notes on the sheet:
(> 500 uR)
Поменять на 2К + включить подтяжку на стороне UI вверх?
заказать перед разводкой платы!
Проверить подключение питания к CP2102
Поменять на 100К?

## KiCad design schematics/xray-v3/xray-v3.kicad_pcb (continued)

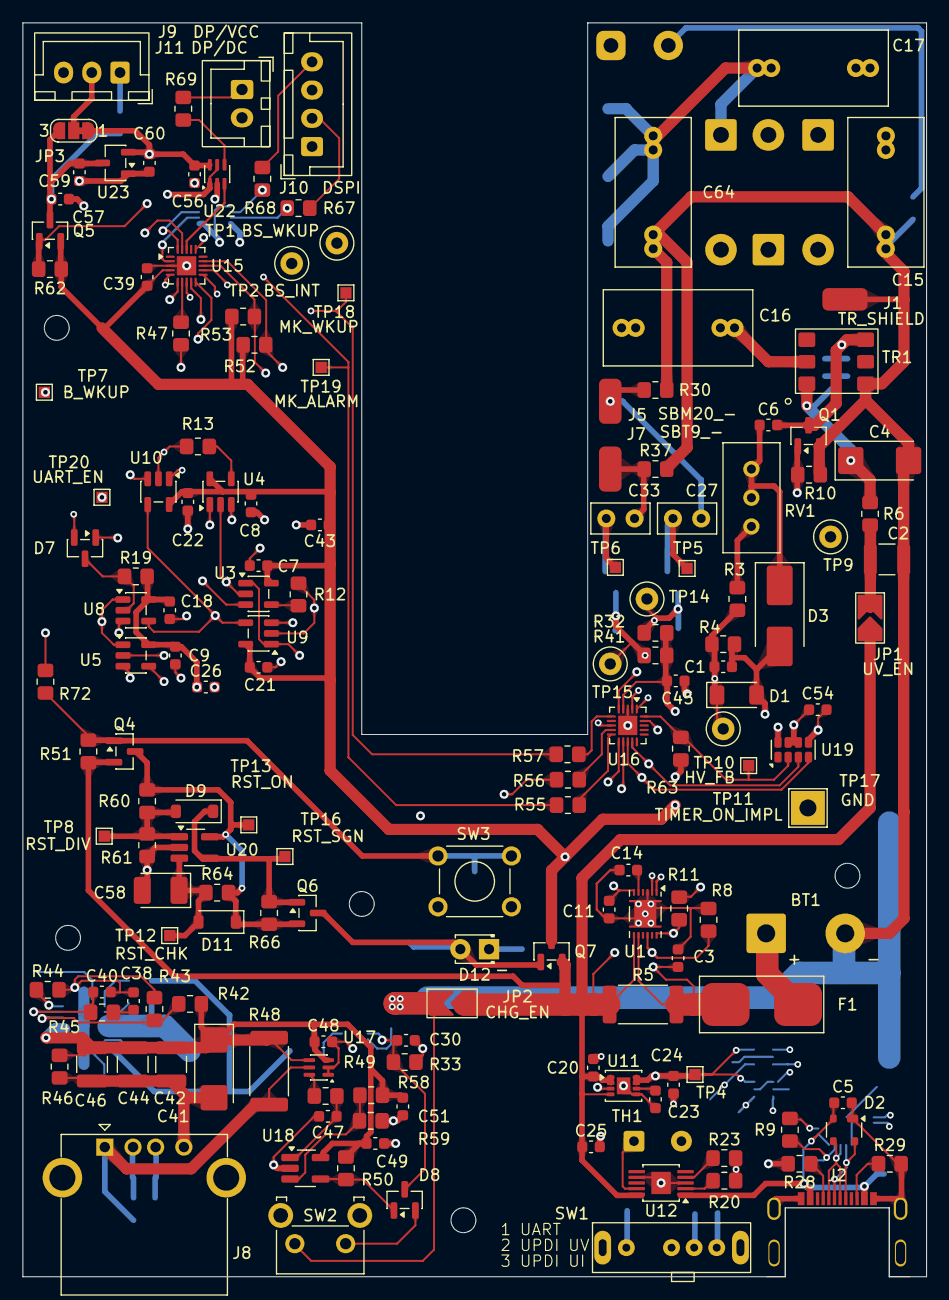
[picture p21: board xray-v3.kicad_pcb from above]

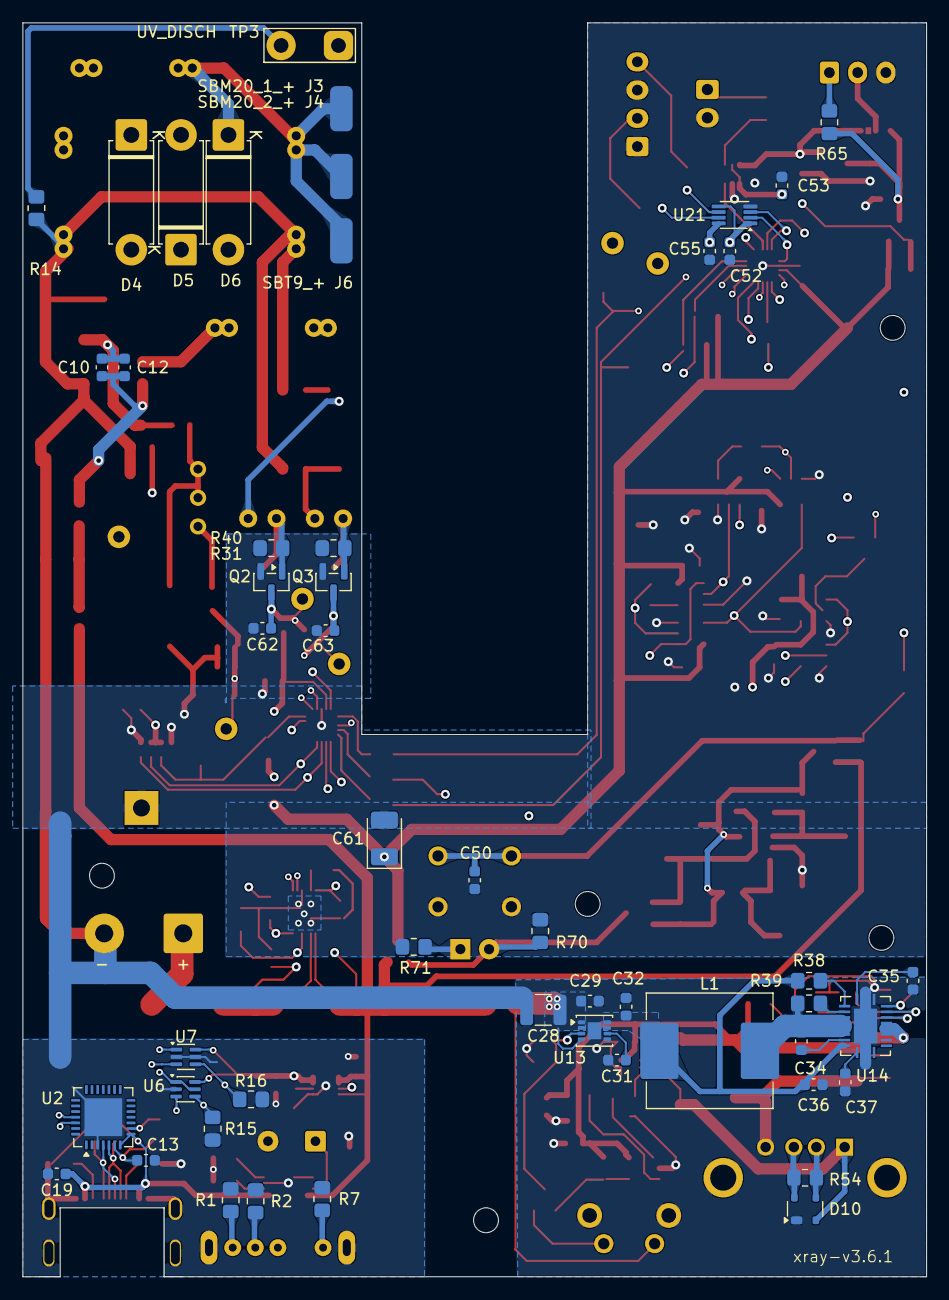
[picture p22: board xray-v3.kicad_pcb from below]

Board: 4 copper layers, 80.0 x 111.0 mm, 216 parts (51 on the bottom side), 109 nets.

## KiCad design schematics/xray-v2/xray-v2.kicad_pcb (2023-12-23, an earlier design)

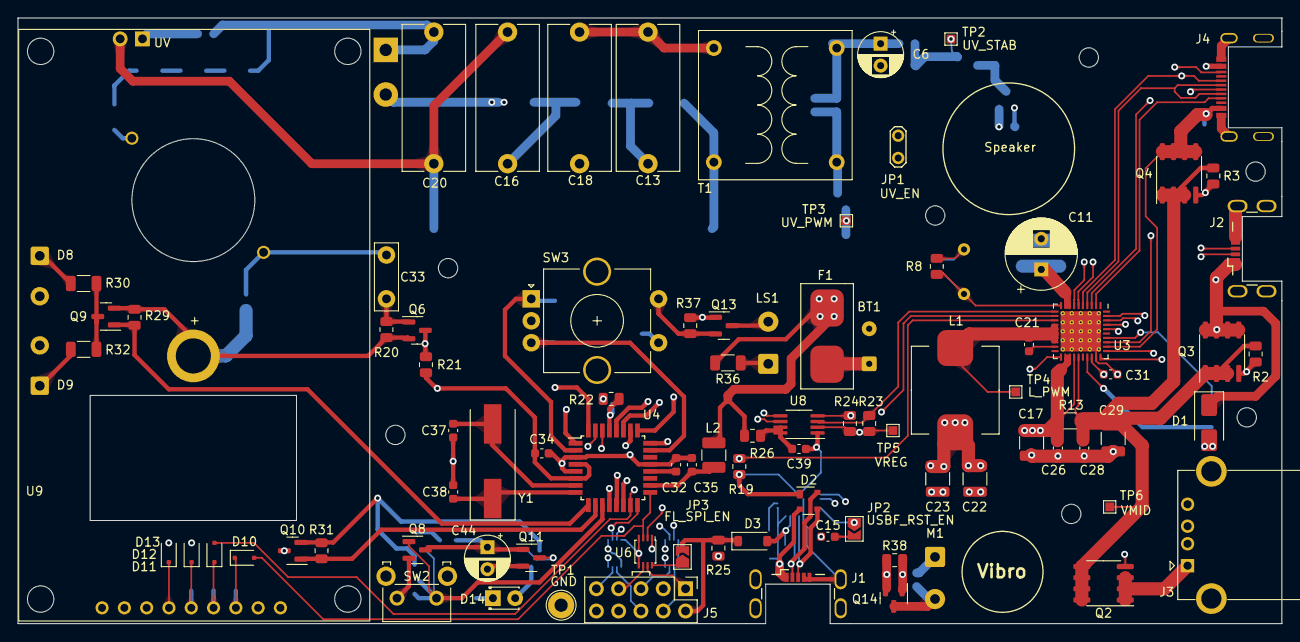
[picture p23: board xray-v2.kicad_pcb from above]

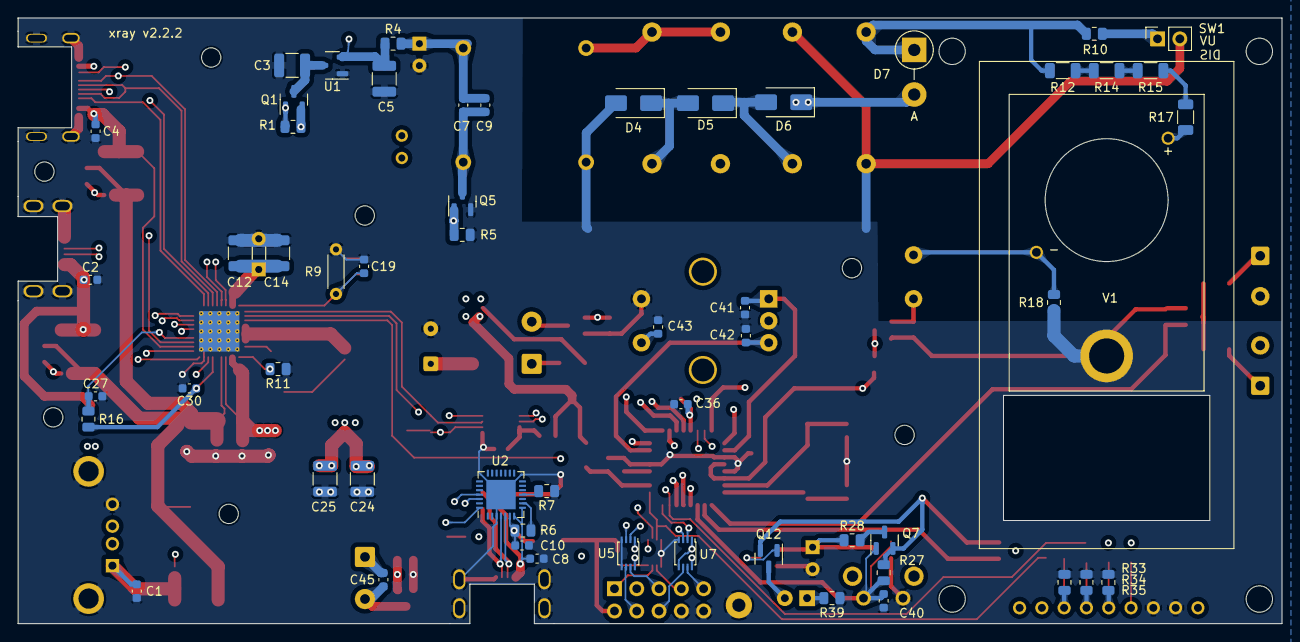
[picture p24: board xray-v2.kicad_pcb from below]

Board: 4 copper layers, 144.0 x 69.0 mm, 154 parts (56 on the bottom side), 101 nets.

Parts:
BT1: Li-Ion, 4.2V, 10000 mAh, 1260100; SolderWire-0.15sqmm_1x02_P4mm_D0.5mm_OD1.5mm
C1, C2, C4, C8, C10, C27: 10 uF; C_0603_1608Metric
C3, C5, C12, C14, C17, C22, C23, C24, C25, C29: 22 uF; C_1210_3225Metric
C6, C44: 100 uF; CP_Radial_D5.0mm_P2.50mm
C7: 21 nF *; C_0603_1608Metric
C9: see note [*]; C_0603_1608Metric
C11: 220 uF; CP_Radial_D8.0mm_P3.50mm
C13, C16, C18, C20: К73-17, 0.1 uF, 630V; C_Rect_L16.5mm_W7.0mm_P15.00mm_MKT
C15, C19, C21, C26, C28, C32, C34, C36, C41, C42, C43, C45: 100 nF; C_0603_1608Metric
C30, C31: 2.2 uF; C_0603_1608Metric
C33: CC81, 10 pF, 630V; C_Disc_D7.5mm_W2.5mm_P5.00mm
C35: 470 nF; C_0603_1608Metric
C37, C38: 18 pF; C_0603_1608Metric
C39: 200 pF; C_0603_1608Metric
C40: 2 uF; C_0603_1608Metric
D1: 15MQ030NPBF; D_SMA
D2: SP0503BAHT; SOT-143
D3: MBR0520; D_SOD-123
D4, D5, D6: US1M; D_SMA
D7: US1M; D_5W_P5.08mm_Vertical_AnodeUp
D8, D9: FLASH; SolderWire-0.5sqmm_1x02_P4.6mm_D0.9mm_OD2.1mm
D10, D11, D12, D13: BAV21WS; D_SOD-323F
D14: L-2060YD; LED_D1.8mm_W3.3mm_H2.4mm
F1: 1808, 6A; FuseHolder1808
H1, H2, H3, H4, H5, H6, H7: MountingHole; MountingHole_2.2mm_M2
J1, J2: USB_B_Micro; USB_Micro-B
J3: USB_A
J4: USB_C_Receptacle_USB2.0; USB_C_P16_MIDMOUNT_1.6
J5: USBASP; PinHeader_2x05_P2.54mm_Vertical
JP1: UV_EN; TestPoint_2Pads_Pitch2.54mm_Drill0.8mm
JP2: USBF_RST_EN; SolderJumper-2_P1.3mm_Open_TrianglePad1.0x1.5mm
JP3: FL_SPI_EN; SolderJumper-2_P1.3mm_Open_TrianglePad1.0x1.5mm
L1: 2.2 uH; Ferrocore-HPI1040
L2: 20 uH; L_1210_3225Metric
LS1: Speaker, D13mm; SolderWire-0.5sqmm_1x02_P4.8mm_D0.9mm_OD2.3mm
M1: VibroMotor, 3V, 8x2.7mm; SolderWire-0.5sqmm_1x02_P4.8mm_D0.9mm_OD2.3mm
Q1, Q7, Q10, Q12: IRLML5203; SOT-23
Q2: IRF7832PbF; SOIC-8_3.9x4.9mm_P1.27mm
Q3, Q4: IRF7425PbF; SOIC-8_3.9x4.9mm_P1.27mm
Q5, Q8, Q9, Q11, Q13, Q14: IRLML0030; SOT-23
Q6: BC847; SOT-23
R1, R2, R3, R7, R16, R21, R22, R25, R27: 10K; R_0805_2012Metric
R4: 68; R_0805_2012Metric
R5, R18, R20, R26, R29, R31, R37, R38: 200K; R_0805_2012Metric
R6: 1K; R_0805_2012Metric
R8: 82K; R_0805_2012Metric
R9: NTCM-100K@25-B4250; R_Axial_DIN0204_L3.6mm_D1.6mm_P5.08mm_Horizontal
R10: 510; R_0805_2012Metric
R11: 114K; R_0805_2012Metric
R12, R14, R15, R17: 2M, 200V; R_1206_3216Metric
R13: 0.01; R_1206_3216Metric
R19: 510K; R_0805_2012Metric
R23, R24: 3.3K; R_0805_2012Metric
R28: 400K ****; R_0805_2012Metric
R30, R32: 16; R_1206_3216Metric
R33, R34, R35: 5K; R_0805_2012Metric
R36: 27; R_1206_3216Metric
R39: 620; R_0805_2012Metric
SW1: SW_Push; PinSocket_1x02_P2.54mm_Vertical
SW2: B3F3150; SW_Tactile_SKHH_Angled
SW3: EC11W****; RotaryEncoder_Alps_EC11E-Switch_Vertical_H20mm_CircularMoun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
T1: Transformer_1P_1S; transformator-4-sh4x4
TP1: GND; TestPoint_Loop_D2.54mm_Drill1.5mm_Beaded
TP2: UV_STAB; TestPoint_Pad_1.0x1.0mm
TP3: UV_PWM; TestPoint_Pad_1.0x1.0mm
TP4: L_PWM; TestPoint_Pad_1.0x1.0mm
TP5: VREG; TestPoint_Pad_1.0x1.0mm
TP6: VMID; TestPoint_Pad_1.0x1.0mm
U1: XC6206P282MR; SOT-23-3
U2: CP2102N-Axx-xQFN28; QFN-28-1EP_5x5mm_P0.5mm_EP3.35x3.35mm
U3: IP5328P; QFN-40-1EP_6x6mm_P0.5mm_EP4.6x4.6mm_ThermalVias
U4: ATmega328P-A; TQFP-32_7x7mm_P0.8mm
U5, U6, U7: SN74LVC2T45DCUR; VSSOP-8_2.4x2.1mm_P0.5mm
U8: PCA9306; MSOP-8_3x3mm_P0.65mm
U9: Display_2.2inch_ili9341
V1: SBT11A; SBT11
Y1: HC-49SM, 8MHz; Crystal_SMD_HC49-SD

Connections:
+5V: D3.1 (K), J5.2, JP3.2 (B), R25.2, U5.8 (VCCB), U7.8 (VCCB)
/DISPLAY_VCC: D13.2 (A), Q10.3 (D), U9.1 (VCC), U9.8 (LED)
CP2102_VREG: C10.1, D3.2 (A), R6.2, U2.6 (VDD)
ENCODER_A: C41.1, SW3.A, U4.2 (PD4)
ENCODER_B: C42.1, SW3.B, U4.23 (PC0)
ENCODER_CLICK: C43.1, SW3.S1, U4.12 (PB0)
FLASHLIGHT: Q9.1 (G), R29.2, U4.9 (PD5)
FLUSH_D+: D2.3 (K), J1.3 (D+), U2.4 (D+)
FLUSH_D-: D2.4 (K), J1.2 (D-), U2.5 (D-)
FLUSH_VBUS: C8.1, D1.2 (A), D2.2 (K), J1.1 (VBUS), U2.7 (VREGIN), U2.8 (VBUS)
GND: BT1.2 (-), C1.2, C2.2, C3.2, C4.2, C5.2, C6.2, C8.2, C10.2, C11.2, C12.2, C14.2, C16.1, C17.2, C19.1, C20.1, C22.2, C23.2, C24.2, C25.2, C26.2, C27.2, C28.2, C29.2, C30.2, C31.2, C32.2, C34.2, C35.2, C36.2, C37.2, C38.2, C39.1, C40.1, C41.2, C42.2, C43.2, C44.2, D2.1 (A), D4.2 (A), J1.4 (ID), J1.5 (GND), J1.6 (Shield), J2.4 (ID), J2.5 (GND), J2.6 (Shield), J3.4 (GND), J3.5 (Shield), J4.A1 (GND), J4.A12 (GND), J4.B1 (GND), J4.B12 (GND), J4.S1 (SHIELD), J5.8, J5.10, Q5.2 (S), Q6.2 (E), Q8.2 (S), Q9.2 (S), Q11.2 (S), Q13.2 (S), Q14.2 (S), R5.1, R7.1, R8.2, R9.2, R11.1, R18.1, R19.2, R20.1, R29.1, R33.2, R34.2, R35.2, R37.1, R38.1, R39.1, SW1.2, SW2.2, SW3.C, SW3.S2, T1.3 (SA), TP1.1, U1.1 (GND), U2.3 (GND), U2.29 (GND), U3.29 (AGND), U3.41 (EP), U4.3 (GND), U4.5 (GND), U4.21 (GND), U5.4 (GND), U5.5 (DIR), U6.4 (GND), U6.5 (DIR), U7.4 (GND), U8.1 (GND), U9.2 (GND), U9.3 (CS), V1.3 (S)
MCU_I2C_SCL: U4.28 (PC5), U8.6 (SCL2)
MCU_I2C_SDA: U4.27 (PC4), U8.5 (SDA2)
MISO: U4.16 (PB4), U7.2 (A1)
MOSI: D11.2 (A), U4.15 (PB3), U6.2 (A1)
unnamed: BT1.1 (+), F1.2
unnamed: C13.1, D4.1 (K), D5.2 (A)
unnamed: C16.2, D5.1 (K), D6.2 (A)
unnamed: C18.2, D6.1 (K), D7.2 (A)
unnamed: C20.2, D7.1 (K), R10.2, R12.1
unnamed: D8.1 (K), R30.2
unnamed: D9.1 (K), R32.2
unnamed: D10.1 (K), R35.1, U9.7 (SCK)
unnamed: D11.1 (K), R34.1, U9.6 (MOSI)
unnamed: D12.1 (K), R33.1, U9.5 (DC)
unnamed: D13.1 (K), U9.4 (RESET#)
unnamed: D14.2 (A), Q12.3 (D)
unnamed: D14.1 (K), R39.2
unnamed: J5.1, U6.7 (B1)
unnamed: J5.7, U6.6 (B2)
unnamed: J5.9, U7.7 (B1)
unnamed: JP1.2 (B), Q1.1 (G), R1.1
unnamed: JP2.1 (A), U2.28 (~DTR)
unnamed: C15.1, JP2.2 (B)
unnamed: JP3.1 (A), U6.8 (VCCB)
unnamed: LS1.1, R36.1
unnamed: C45.1, M1.2 (-), Q14.3 (D)
unnamed: C3.1, Q1.3 (D), U1.3 (VI)
unnamed: C7.1, C9.1, Q5.3 (D), T1.2 (AB)
unnamed: C33.2, Q6.1 (B), R20.2
unnamed: Q7.3 (D), R28.2
unnamed: Q9.3 (D), R30.1, R32.1
unnamed: C44.1, Q8.3 (D), Q11.1 (G), R28.1
unnamed: LS1.2, Q13.3 (D)
unnamed: R10.1, SW1.1
unnamed: R12.2, R14.1
unnamed: R14.2, R15.1
unnamed: R15.2, R17.1
unnamed: C6.1, C7.2, C9.2, R4.2, T1.1 (AA)
unnamed: C13.2, C18.1, T1.4 (SB)
unnamed: C5.1, R4.1, TP2.1, U1.2 (VO)
unnamed: R6.1, U2.9 (~RST)
unnamed: R7.2, U2.11 (~SUSPEND)
unnamed: C21.1, U3.19 (BST)
unnamed: C21.2, L1.2, TP4.1, U3.14 (LX_1), U3.15 (LX_2), U3.16 (LX_3), U3.17 (LX_4), U3.18 (LX_5)
unnamed: C19.2, R8.1, R9.1, U3.10 (NTC)
unnamed: R11.2, U3.21 (RSET)
unnamed: C32.1, U4.20 (AREF)
unnamed: C35.1, L2.1, U4.18 (AVCC)
unnamed: C37.1, U4.7 (XTAL1/PB6), Y1.2
unnamed: C38.1, U4.8 (XTAL2/PB7), Y1.1
unnamed: C39.2, R26.2, U8.7 (VREF2), U8.8 (EN)
unnamed: R17.2, V1.1 (A)
unnamed: C33.1, R18.2, V1.2 (C)
RADIATION_VALUE: Q6.3 (C), R21.1, U4.32 (PD2)
RESET: C36.1, Q11.3 (D), Q12.1 (G), R22.1, U4.29 (~RESET/PC6), U5.2 (A1)
RESET_V: C15.2, J5.5, R25.1, U5.7 (B1)
RXD: U4.30 (PD0), U5.3 (A2)
RXD_V: J5.4, U2.26 (TXD), U5.6 (B2)
SCK: D10.2 (A), U4.17 (PB5), U6.3 (A2)
SPEAKER: Q13.1 (G), R37.2, U4.1 (PD3)
TFT_DC: D12.2 (A), U4.26 (PC3)
TFT_ENABLE#: Q10.1 (G), R31.1, U4.10 (PD6)
TXD: U4.31 (PD1), U7.3 (A2)
TXD_V: J5.6, U2.25 (RXD), U7.6 (B2)
USB_I2C_SCL: R23.2, U3.11 (L1), U8.3 (SCL1)
USB_I2C_SDA: R24.2, U3.12 (L2), U8.4 (SDA1)
USB_INT: R19.1, U3.13 (L3), U4.13 (PB1)
USB_IN_CC1: J4.A5 (CC1), U3.2 (CC1)
USB_IN_CC2: J4.B5 (CC2), U3.3 (CC2)
USB_IN_D+: J4.A6 (D+), J4.B6 (D+), U3.5 (DPC)
USB_IN_D-: J4.A7 (D-), J4.B7 (D-), U3.4 (DMC)
USB_IN_VBUS: C4.1, J4.A4 (VBUS), J4.A9 (VBUS), J4.B4 (VBUS), J4.B9 (VBUS), Q4.5 (D), Q4.6 (D), Q4.7 (D), Q4.8 (D), U3.32 (VBUS)
USB_IN_VBUS_G: Q4.4 (G), R3.1, U3.33 (VBUSG)
USB_M_IN_D+: J2.3 (D+), U3.7 (DPB)
USB_M_IN_D-: J2.2 (D-), U3.6 (DMB)
USB_M_IN_VBUS: C2.1, D1.1 (K), J2.1 (VBUS), Q3.5 (D), Q3.6 (D), Q3.7 (D), Q3.8 (D), U3.30 (VIN)
USB_M_IN_VBUS_G: Q3.4 (G), R2.1, U3.31 (VING)
USB_OUT_D+: J3.3 (D+), U3.39 (DPA1)
USB_OUT_D-: J3.2 (D-), U3.38 (DMA1)
USB_OUT_VBUS: C1.1, J3.1 (VBUS), Q2.1 (S), Q2.2 (S), Q2.3 (S), U3.37 (VOUT1)
USB_OUT_VBUS_G: Q2.4 (G), U3.36 (VOUT1G)
USB_OUT_VOUT2: C27.1, R16.2, U3.34 (VOUT2)
USB_VMID: C28.1, C29.1, Q2.5 (D), Q2.6 (D), Q2.7 (D), Q2.8 (D), Q3.1 (S), Q3.2 (S), Q3.3 (S), Q4.1 (S), Q4.2 (S), Q4.3 (S), R2.2, R3.2, R13.1, TP6.1, U3.25 (VSN)
USB_VSYS: C11.1, C12.1, C14.1, C17.1, C26.1, R13.2, U3.8 (VSYS_1), U3.9 (VSYS_2), U3.22 (VSYS_3), U3.23 (VSYS_4), U3.24 (VSP)
UV_ENABLE#: JP1.1 (A), U4.25 (PC2)
UV_PWM: Q5.1 (G), R5.2, TP3.1, U4.14 (PB2)
VCC: C22.1, C23.1, C24.1, C25.1, C31.1, C34.1, C45.2, D8.2 (A), D9.2 (A), F1.1, L1.1, L2.2, M1.1 (+), Q1.2 (S), Q7.2 (S), Q10.2 (S), Q12.2 (S), R1.2, R21.2, R22.2, R26.1, R27.2, R31.2, R36.2, U3.28 (BAT), U4.4 (VCC), U4.6 (VCC), U5.1 (VCCA), U6.1 (VCCA), U7.1 (VCCA), U7.5 (DIR)
VIBRO: Q14.1 (G), R38.2, U4.24 (PC1)
VREG: C30.1, R16.1, R23.1, R24.1, TP5.1, U3.27 (VREG), U8.2 (VREF1)
WAKEUP_BUTTON: C40.2, Q7.1 (G), Q8.1 (G), R27.1, SW2.1, U4.11 (PD7)

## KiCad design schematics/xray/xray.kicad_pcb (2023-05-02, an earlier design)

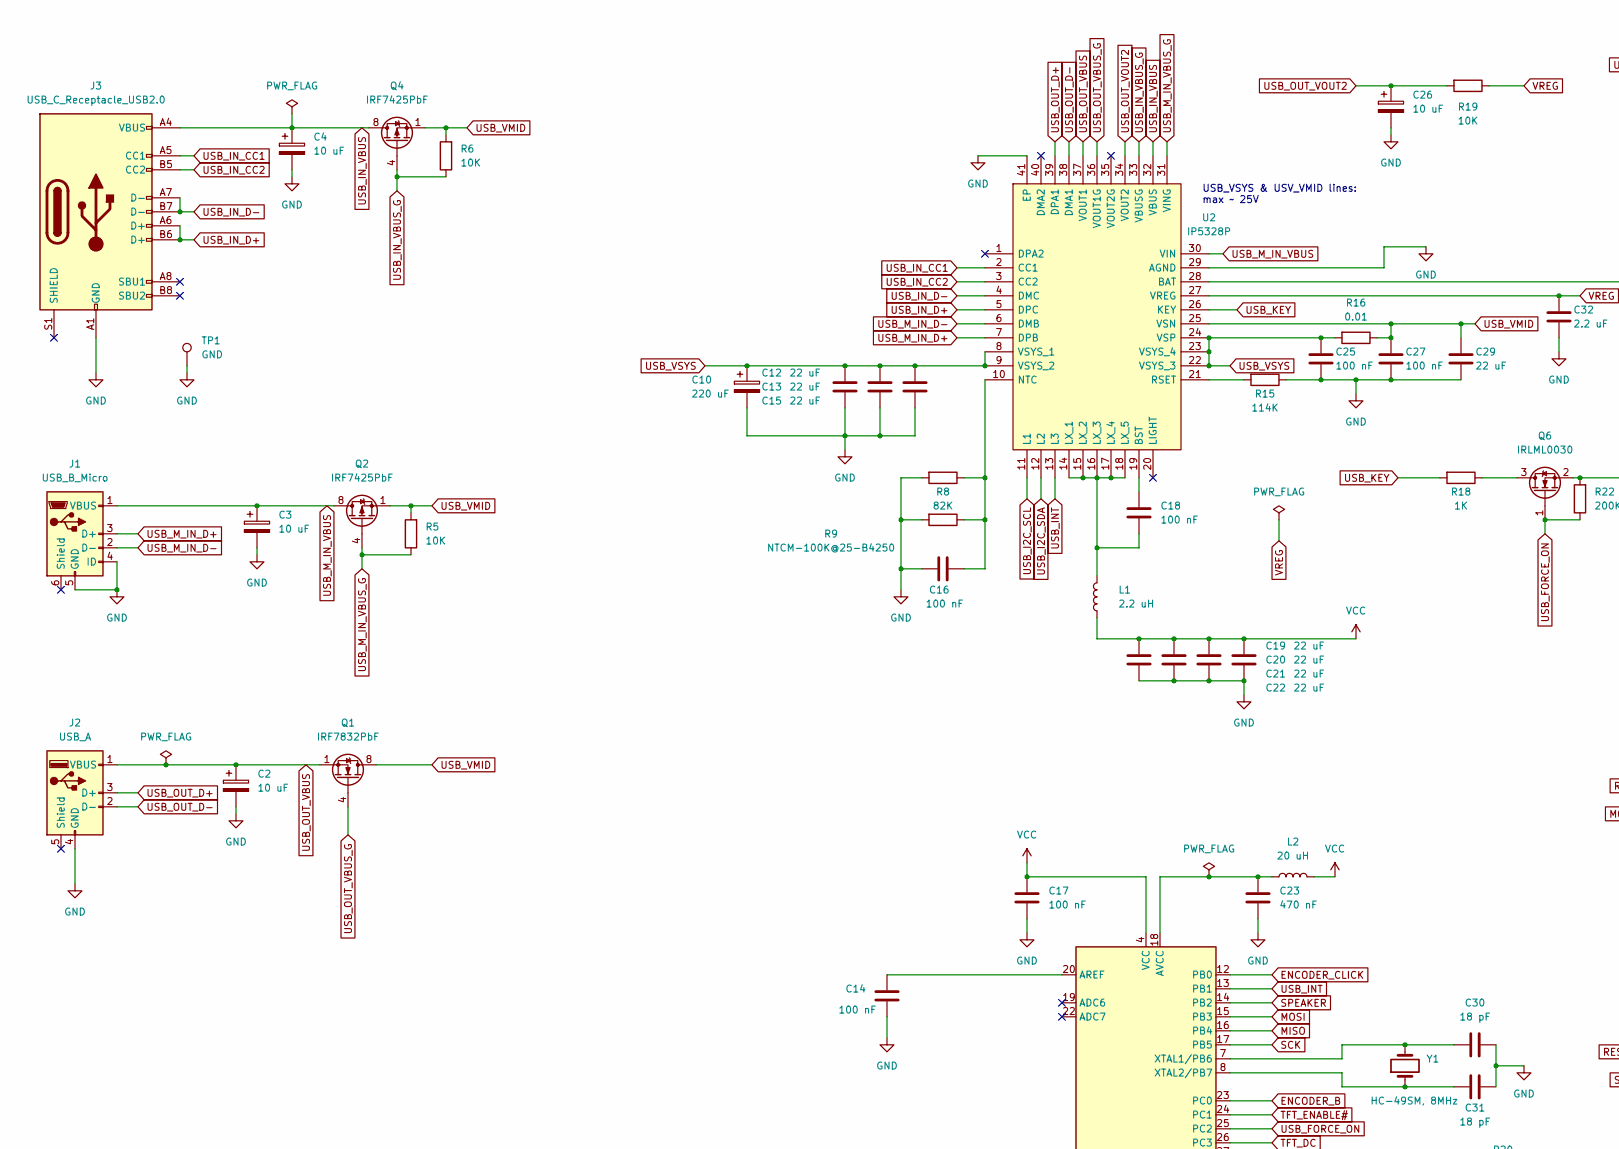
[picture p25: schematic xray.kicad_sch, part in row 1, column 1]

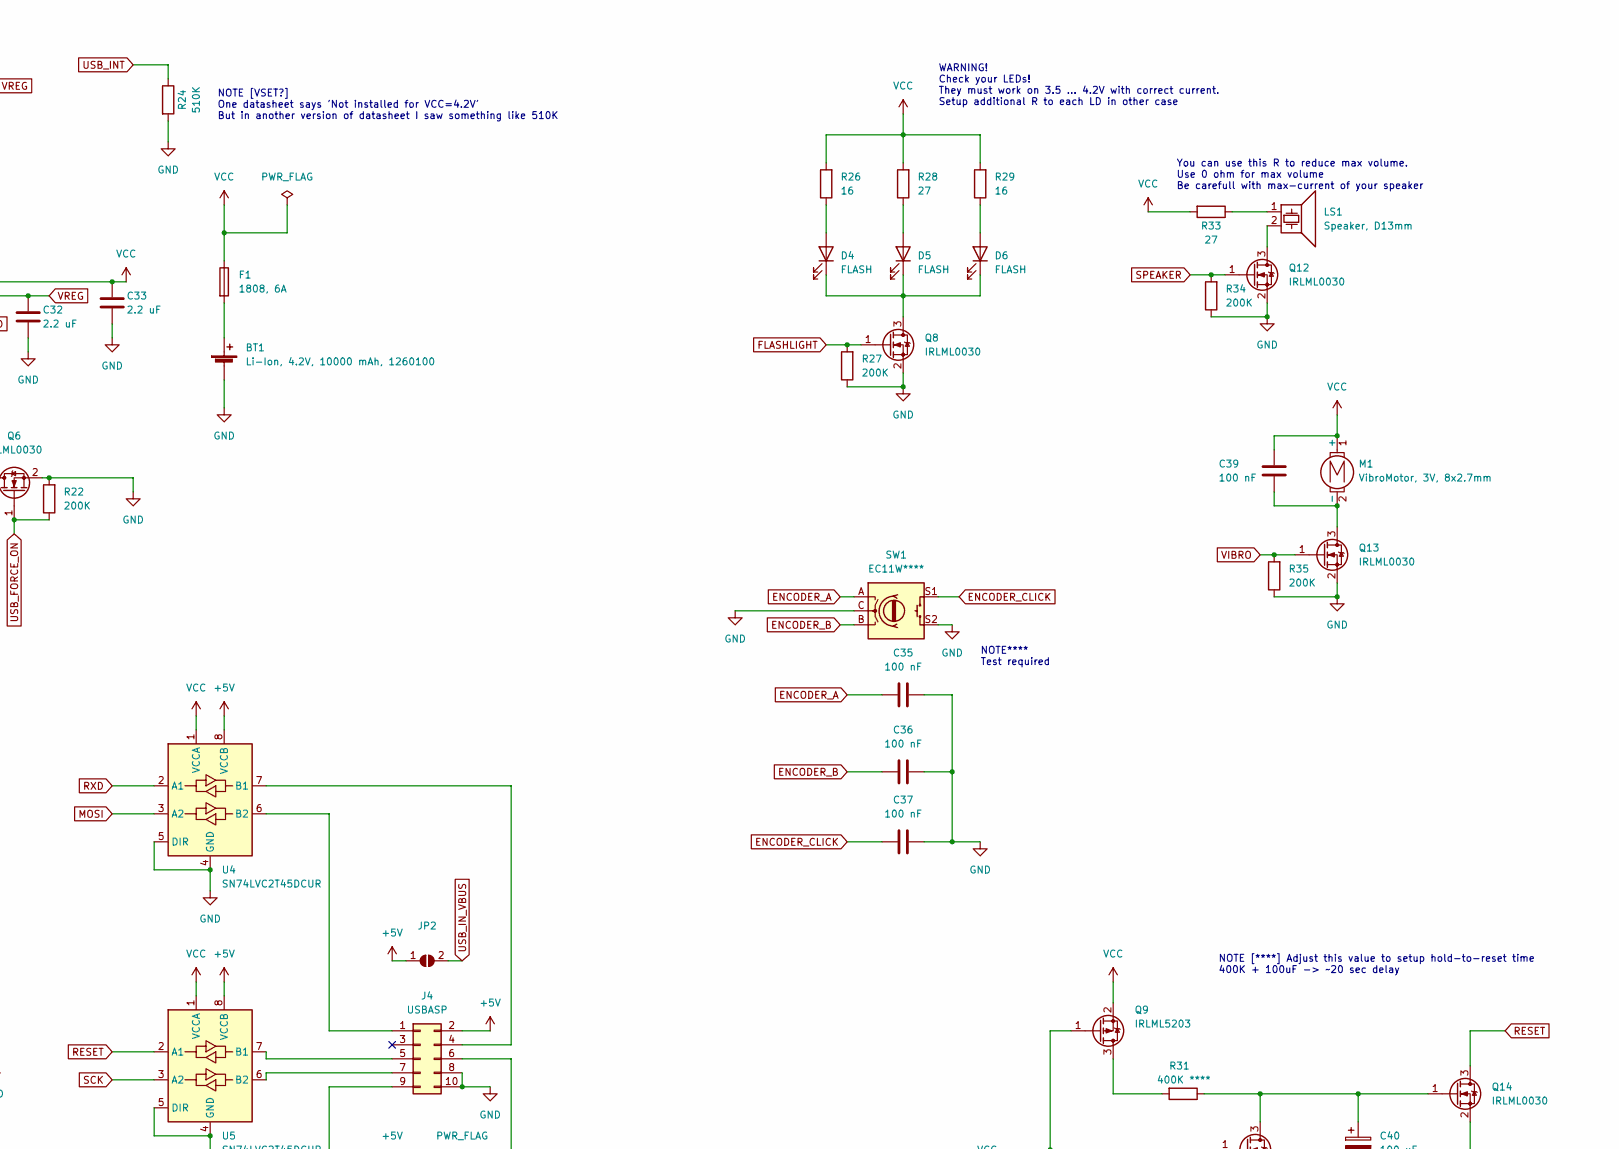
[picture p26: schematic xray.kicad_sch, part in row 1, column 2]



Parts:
BT1: Li-Ion, 4.2V, 10000 mAh, 1260100; SolderWire-0.15sqmm_1x02_P4mm_D0.5mm_OD1.5mm
C1, C40: 100 uF; CP_Radial_D5.0mm_P2.50mm
C2, C3, C4, C26: 10 uF; CP_Radial_D5.0mm_P2.00mm
C5: 21 nF *; C_0603_1608Metric
C6: see note [*]; C_0603_1608Metric
C7: 200 pF; C_0603_1608Metric
C8, C9, C11: К73-17, 0.1 uF, 630V; C_Rect_L16.5mm_W9.0mm_P15.00mm_MKT
C10: 220 uF; CP_Radial_D8.0mm_P3.50mm
C12, C13, C15, C19, C20, C21, C22, C29: 22 uF; C_1210_3225Metric
C14, C16, C17, C18, C25, C27, C28, C35, C36, C37, C38, C39: 100 nF; C_0603_1608Metric
C23: 470 nF; C_0603_1608Metric
C24: CC81, 10 pF, 630V; C_Disc_D7.5mm_W2.5mm_P5.00mm
C30, C31: 18 pF; C_0603_1608Metric
C32, C33: 2.2 uF; C_0603_1608Metric
C34: 330 pF***; C_0603_1608Metric
D1, D2: US1M; D_SMA
D3: US1M; D_5W_P5.08mm_Vertical_AnodeUp
D4, D5, D6: FLASH; SolderWire-0.5sqmm_1x02_P4.6mm_D0.9mm_OD2.1mm
F1: 1808, 6A; FuseHolder1808
H1, H3: MountingHole; MountingHole_3.2mm_M3
J1: USB_B_Micro; USB_Micro-B
J2: USB_A
J3: USB_C_Receptacle_USB2.0; USB_C_P16_MIDMOUNT_1.6
J4: USBASP; PinHeader_2x05_P2.54mm_Vertical
JP1, JP2: SolderJumper_2_Open; SolderJumper-2_P1.3mm_Open_TrianglePad1.0x1.5mm
L1: 2.2 uH; L_Sumida_CDMC6D28_7.25x6.5mm
L2: 20 uH; L_1210_3225Metric
LS1: Speaker, D13mm; SolderWire-0.5sqmm_1x02_P4.8mm_D0.9mm_OD2.3mm
M1: VibroMotor, 3V, 8x2.7mm; SolderWire-0.5sqmm_1x02_P4.8mm_D0.9mm_OD2.3mm
Q1: IRF7832PbF; SOIC-8_3.9x4.9mm_P1.27mm
Q2, Q4: IRF7425PbF; SOIC-8_3.9x4.9mm_P1.27mm
Q3, Q6, Q8, Q11, Q12, Q13, Q14: IRLML0030; SOT-23
Q5: BC857; SOT-23
Q7: BC847; SOT-23
Q9, Q10: IRLML5203; SOT-23
R1: 68 **; R_0805_2012Metric
R2, R3: 3.3K; R_0805_2012Metric
R4, R7, R14, R22, R23, R27, R32, R34, R35: 200K; R_0805_2012Metric
R5, R6, R19, R20, R25, R30: 10K; R_0805_2012Metric
R8: 82K; R_0805_2012Metric
R9: NTCM-100K@25-B4250; R_Axial_DIN0204_L3.6mm_D1.6mm_P5.08mm_Horizontal
R10, R11, R12, R13: 2M, 200V; R_1206_3216Metric
R15: 114K; R_0805_2012Metric
R16: 0.01; R_1206_3216Metric
R17: 67K**; R_0805_2012Metric
R18: 1K; R_0805_2012Metric
R21: 10K***; R_0805_2012Metric
R24: 510K; R_0805_2012Metric
R26, R29: 16; R_1206_3216Metric
R28, R33: 27; R_1206_3216Metric
R31: 400K ****; R_0805_2012Metric
SW1: EC11W****; RotaryEncoder_Alps_EC11E-Switch_Vertical_H20mm_CircularMoun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
SW2: B3F3150; SW_Tactile_SKHH_Angled
T1: Transformer_1P_1S; transformator-4-sh4x4
TP1: GND; TestPoint_Pad_4.0x4.0mm
U1: PCA9306; MSOP-8_3x3mm_P0.65mm
U2: IP5328P; QFN-40-1EP_6x6mm_P0.5mm_EP4.6x4.6mm_ThermalVias; Manufacturer_Part_Number IP5328P
U3: ATmega328P-A; TQFP-32_7x7mm_P0.8mm
U4, U5, U6: SN74LVC2T45DCUR; VSSOP-8_2.4x2.1mm_P0.5mm
U7: Display_1.18inch_st7535; Display_1.18inch_st7735
V1: SBT11A; SBT11
Y1: HC-49SM, 8MHz; Crystal_SMD_HC49-SD

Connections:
+5V: J4.2, JP2.1 (A), U4.8 (VCCB), U5.8 (VCCB), U6.8 (VCCB)
ENCODER_A: C35.1, SW1.A, U3.2 (PD4)
ENCODER_B: C36.1, SW1.B, U3.23 (PC0)
ENCODER_CLICK: C37.1, SW1.S1, U3.12 (PB0)
FLASHLIGHT: Q8.1 (G), R27.2, U3.9 (PD5)
GND: BT1.2 (-), C1.2, C2.2, C3.2, C4.2, C7.1, C9.2, C10.2, C11.1, C12.2, C13.2, C14.2, C15.2, C16.1, C17.2, C19.2, C20.2, C21.2, C22.2, C23.2, C25.2, C26.2, C27.2, C28.2, C29.2, C30.2, C31.2, C32.2, C33.2, C34.1, C35.2, C36.2, C37.2, C38.1, C40.2, J1.4 (ID), J1.5 (GND), J2.4 (GND), J3.A1 (GND), J3.A12 (GND), J3.B1 (GND), J3.B12 (GND), J4.8, J4.10, Q3.2 (S), Q6.2 (S), Q7.2 (E), Q8.2 (S), Q11.2 (S), Q12.2 (S), Q13.2 (S), Q14.2 (S), R4.1, R8.2, R9.2, R14.1, R15.1, R22.2, R23.1, R24.2, R27.1, R34.1, R35.1, SW1.C, SW1.S2, SW2.2, T1.3 (SA), TP1.1, U1.1 (GND), U2.29 (AGND), U2.41 (EP), U3.3 (GND), U3.5 (GND), U3.21 (GND), U4.4 (GND), U4.5 (DIR), U5.4 (GND), U5.5 (DIR), U6.4 (GND), U7.1 (CS), U7.9 (GND), U7.10 (GND)
MCU_I2C_SCL: U1.6 (SCL2), U3.28 (PC5)
MCU_I2C_SDA: U1.5 (SDA2), U3.27 (PC4)
MISO: U3.16 (PB4), U6.2 (A1)
MOSI: U3.15 (PB3), U4.3 (A2), U7.4 (MOSI)
unnamed: BT1.1 (+), F1.2
unnamed: C24.1, R14.2, V1.2
unnamed: C8.1, D1.2 (A), T1.4 (SB)
unnamed: C9.1, D1.1 (K), D2.2 (A)
unnamed: C8.2, D2.1 (K), D3.2 (A)
unnamed: C11.2, D3.1 (K), JP1.1 (A)
unnamed: D4.2 (A), R26.1
unnamed: D4.1 (K), D5.1 (K), D6.1 (K), Q8.3 (D)
unnamed: D5.2 (A), R28.1
unnamed: D6.2 (A), R29.1
unnamed: J4.1, U4.6 (B2)
unnamed: J4.4, U4.7 (B1)
unnamed: J4.5, U5.7 (B1)
unnamed: J4.6, U6.6 (B2)
unnamed: J4.7, U5.6 (B2)
unnamed: J4.9, U6.7 (B1)
unnamed: JP1.2 (B), R10.1
unnamed: LS1.1, R33.1
unnamed: C39.1, M1.2 (-), Q13.3 (D)
unnamed: C5.1, C6.1, Q3.3 (D), T1.2 (AB)
unnamed: C24.2, Q5.1 (B), R17.1
unnamed: Q5.3 (C), R21.1
unnamed: Q6.3 (D), R18.1
unnamed: C34.2, Q7.1 (B), R21.2, R23.2
unnamed: Q9.3 (D), R31.2
unnamed: Q10.3 (D), U7.2 (RESET), U7.11 (VCC)
unnamed: C40.1, Q11.3 (D), Q14.1 (G), R31.1
unnamed: LS1.2, Q12.3 (D)
unnamed: R10.2, R11.1
unnamed: R11.2, R12.1
unnamed: R12.2, R13.1
unnamed: R13.2, V1.1
unnamed: C1.1, C5.2, C6.2, R1.2, T1.1 (AA)
unnamed: C7.2, R7.2, U1.7 (VREF2), U1.8 (EN)
unnamed: C18.1, U2.19 (BST)
unnamed: C18.2, L1.2, U2.14 (LX_1), U2.15 (LX_2), U2.16 (LX_3), U2.17 (LX_4), U2.18 (LX_5)
unnamed: C16.2, R8.1, R9.1, U2.10 (NTC)
unnamed: R15.2, U2.21 (RSET)
unnamed: C14.1, U3.20 (AREF)
unnamed: C23.1, L2.1, U3.18 (AVCC)
unnamed: C30.1, U3.7 (XTAL1/PB6), Y1.2
unnamed: C31.1, U3.8 (XTAL2/PB7), Y1.1
RADIATION_VALUE: Q7.3 (C), R25.1, U3.32 (PD2)
RESET: C28.1, Q14.3 (D), R20.1, U3.29 (~RESET/PC6), U5.2 (A1)
RXD: U3.30 (PD0), U4.2 (A1)
SCK: U3.17 (PB5), U5.3 (A2), U7.5 (SCK)
SPEAKER: Q12.1 (G), R34.2, U3.14 (PB2)
TFT_DC: U3.26 (PC3), U7.3 (DC)
TFT_ENABLE#: Q10.1 (G), R32.1, U3.24 (PC1)
TXD: U3.31 (PD1), U6.3 (A2)
USB_FORCE_ON: Q6.1 (G), R22.1, U3.25 (PC2)
USB_I2C_SCL: R2.2, U1.3 (SCL1), U2.11 (L1)
USB_I2C_SDA: R3.2, U1.4 (SDA1), U2.12 (L2)
USB_INT: R24.1, U2.13 (L3), U3.13 (PB1)
USB_IN_CC1: J3.A5 (CC1), U2.2 (CC1)
USB_IN_CC2: J3.B5 (CC2), U2.3 (CC2)
USB_IN_D+: J3.A6 (D+), J3.B6 (D+), U2.5 (DPC)
USB_IN_D-: J3.A7 (D-), J3.B7 (D-), U2.4 (DMC)
USB_IN_VBUS: C4.1, J3.A4 (VBUS), J3.A9 (VBUS), J3.B4 (VBUS), J3.B9 (VBUS), JP2.2 (B), Q4.5 (D), Q4.6 (D), Q4.7 (D), Q4.8 (D), U2.32 (VBUS)
USB_IN_VBUS_G: Q4.4 (G), R6.1, U2.33 (VBUSG)
USB_KEY: R18.2, U2.26 (KEY)
USB_M_IN_D+: J1.3 (D+), U2.7 (DPB)
USB_M_IN_D-: J1.2 (D-), U2.6 (DMB)
USB_M_IN_VBUS: C3.1, J1.1 (VBUS), Q2.5 (D), Q2.6 (D), Q2.7 (D), Q2.8 (D), U2.30 (VIN)
USB_M_IN_VBUS_G: Q2.4 (G), R5.1, U2.31 (VING)
USB_OUT_D+: J2.3 (D+), U2.39 (DPA1)
USB_OUT_D-: J2.2 (D-), U2.38 (DMA1)
USB_OUT_VBUS: C2.1, J2.1 (VBUS), Q1.1 (S), Q1.2 (S), Q1.3 (S), U2.37 (VOUT1)
USB_OUT_VBUS_G: Q1.4 (G), U2.36 (VOUT1G)
USB_OUT_VOUT2: C26.1, R19.2, U2.34 (VOUT2)
USB_VMID: C27.1, C29.1, Q1.5 (D), Q1.6 (D), Q1.7 (D), Q1.8 (D), Q2.1 (S), Q2.2 (S), Q2.3 (S), Q4.1 (S), Q4.2 (S), Q4.3 (S), R5.2, R6.2, R16.1, U2.25 (VSN)
USB_VSYS: C10.1, C12.1, C13.1, C15.1, C25.1, R16.2, U2.8 (VSYS_1), U2.9 (VSYS_2), U2.22 (VSYS_3), U2.23 (VSYS_4), U2.24 (VSP)
UV_PWM: Q3.1 (G), R4.2, U3.1 (PD3)
VCC: C17.1, C19.1, C20.1, C21.1, C22.1, C33.1, C39.2, F1.1, L1.1, L2.2, M1.1 (+), Q5.2 (E), Q9.2 (S), Q10.2 (S), R1.1, R7.1, R17.2, R20.2, R25.2, R26.2, R28.2, R29.2, R30.2, R32.2, R33.2, U2.28 (BAT), U3.4 (VCC), U3.6 (VCC), U4.1 (VCCA), U5.1 (VCCA), U6.1 (VCCA), U6.5 (DIR)
VIBRO: Q13.1 (G), R35.2, U3.10 (PD6)
VREG: C32.1, R2.1, R3.1, R19.1, U1.2 (VREF1), U2.27 (VREG)
WAKEUP_BUTTON: C38.2, Q9.1 (G), Q11.1 (G), R30.1, SW2.1, U3.11 (PD7)

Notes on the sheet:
FIXME LIST on v2.0 KNOWN ERRORS: 1. required capacitor 22pF@500V on Y1 Fixes: 1. integrate UV stabilizator 2. replace L1 to AMPLF1040 3. rewrite amplifier-detector to work on positive impulse 4. remove unused JP2 5. add soldered jumper on UV_PWM line 6. add UV discharge button 7. replace GND testpo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
NOTE**** Test required
NOTE [****] Adjust this value to setup hold-to-reset time 400K + 100uF -> ~20 sec delay
T0 - clock [no pin output, ISR only] T1 - volume, vibro & LED flashlight. * OC1A -> volume generation with variable freq * OC1B -> flashlight brightness [used different duty of same timer] T2 - UV_PWM (hardware PWM on OC2B with fixed duty) Await impulses via ISR on INT0
NOTE*** Nmax for SBT11A == 2.5*10^4 imp/sec == 25Khz LF filter: 10K + 330pF ~ 48Khz Freq of UV source ~ 100hz
NOTE ** I have to find nominal of this R to reduce signal time MAX Timp = 1 / (2.5 * 10^4) = 40 mkS Expected Timp ~ 10-20mkS
T1: N in [1-2] : ~18 turns (change it to adjust output voltage) N out [3-4] : 1000 turns Ferite core : М2000НМ, Ш4х4, clearance - manual ~1-2mm, adjust it. Coil frame : Ш4х4 2 x https://www.chipdip.ru/product/m2000nm-sh4x4-1-sht 1 x https://www.chipdip.ru/product/katushka-karkas-pod-sh-4x4
NOTE* These capacitors used to adjust output voltage NOTE** This resistor can be used to adjust output voltage Use 10...100 ohm to reduce or increase it
WARNING! Check your LEDs! They must work on 3.5 ... 4.2V with correct current. Setup additional R to each LD in other case
You can use this R to reduce max volume. Use 0 ohm for max volume Be carefull with max-current of your speaker
NOTE [VSET?] One datasheet says 'Not installed for VCC=4.2V' But in another version of datasheet I saw something like 510K
USB_VSYS & USV_VMID lines: max ~ 25V

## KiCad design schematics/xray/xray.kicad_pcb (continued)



Board: 4 copper layers, 130.0 x 65.0 mm, 122 parts (49 on the bottom side), 87 nets.

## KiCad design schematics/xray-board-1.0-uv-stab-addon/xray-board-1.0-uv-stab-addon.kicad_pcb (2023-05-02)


Board: 2 copper layers, 25.4 x 9.6 mm, 13 parts (1 on the bottom side), 7 nets.

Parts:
C1: 50 nF; C_0603_1608Metric
C2, C3: 22 uF; C_1210_3225Metric
C4: 100 uF; CP_Radial_D5.0mm_P2.50mm
J1, J2, J3, J4: Conn_01x01_Pin; Pin_D1.0mm_L10.0mm
Q1: IRLML0030; SOT-23
Q2: IRLML5203; SOT-23
R1: 100K; R_0805_2012Metric
R2: 68; R_0805_2012Metric
U1: AMS1117-3.3; SOT-223-3_TabPin2

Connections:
GND: C1.2, C2.2, C3.2, C4.2, J3.1, Q1.2 (S), U1.1 (GND)
unnamed: J1.1, Q1.1 (G)
unnamed: C4.1, J4.1, R2.2
unnamed: C1.1, Q1.3 (D), Q2.1 (G), R1.2
unnamed: C2.1, Q2.3 (D), U1.3 (VI)
unnamed: C3.1, R2.1, U1.2 (VO)
VCC: J2.1, Q2.2 (S), R1.1

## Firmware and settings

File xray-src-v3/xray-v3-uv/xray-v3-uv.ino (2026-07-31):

#include "uv_gen.h"
#include "uart_ctrl.h"
#include "timer_ctrl.h"
#include "rad_control.h"
#include "i2c_ctrl.h"
#include "rad_data.h"
#include "powersave.h"

void setup() {
  uv_gen_init();
  timerctrl_init();
  uart_ctrl_init();
  i2c_ctrl_init();
  rad_data_init();
  rad_control_init();
}

void loop() {
  rad_data_on_main_loop();
  uart_ctrl_on_main_loop();
  i2c_ctrl_on_main_loop();
  rad_control_on_main_loop();

  powersave_on_main_loop();
}

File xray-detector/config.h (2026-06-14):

#ifndef CONFIG_H_
#define CONFIG_H_

#define SYSTEM_SERIAL_ENABLED true
#define SYSTEM_SERIAL_FREQ    9600

#define POWERSAVE_LIGHTSLEEP_DISABLE_IO true

// simulate encoder wia 3-buttons
#define USERINPUT_ENCODER_SIMUL false

// display type
#define DISPLAY_TYOE_ILI9341_ADAFRUIT false
#define DISPLAY_TYPE_ILI9341_CUSTOM true
#define DISPLAY_TYPE_ST7335_ADAFRUIT false
#define DISPLAY_TYPE_ST7335_CUSTOM false

// Enable hign voltage generator
#define UV_HIGH_VOLTAGE_OUTPUT_ENABLED false

// init fake accumulated data buffer on startup
#define EEPROM_CONTROL_INIT_FAKE_BUFFER false

#define ALARM_EVERY_MINUTE_ENABLED false

#endif /* CONFIG_H_ */

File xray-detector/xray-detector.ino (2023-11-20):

#include "uv_control.h"
#include "rad_control.h"
#include "clock.h"
#include "svf_control.h"
#include "display.h"
#include "userinput.h"
#include "gui_manager.h"
#include "powersave.h"
#include "eeprom_control.h"
#include "alarm_manager.h"
#include "charger_control.h"
#include "rad_history.h"
#include "ip5328p_dump.h"
#include "config.h"
#include "graph.h"

#define UV_DEBUG_MODE false

void setup() {
//  ip5328_dump();
//  return;
  
#if SYSTEM_SERIAL_ENABLED
  Serial.begin(SYSTEM_SERIAL_FREQ);
#endif

#if UV_DEBUG_MODE
  uv_control_init();
  uv_control_update_pwm(105000, 7);
  uv_control_enable_pwm();
  while(true);
#endif

  clock_init();
  svf_control_init();
  eeprom_control_init();
  rad_control_init();
  svf_control_init();
  userinput_init();
  display_init(); 
  gui_manager_init();
  alarm_manager_init();
  charger_control_init();
  uv_control_init();
  rad_history_init();

#if SYSTEM_SERIAL_ENABLED
  Serial.println("Init done");
#endif
}

void loop() {
  alarm_manager_on_main_loop();
  
  if (!powersave_on_main_loop()) {
    rad_history_on_main_loop();
    graph_refresh_from_history();
    return;
  }
  
  charger_control_on_main_loop();
  svf_control_on_main_loop();
  rad_history_on_main_loop();
  gui_manager_on_main_loop();
}

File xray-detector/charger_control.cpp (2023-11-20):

#include "charger_control.h"

#include "Arduino.h"
#include <Wire.h>
#include "powersave.h"
#include "clock.h"

#define CHARGER_I2C_ADDR 0x75

#define CHARGER_I2C_REG_VOLTAGE_1 0x64
#define CHARGER_I2C_REG_VOLTAGE_2 0x65

#define CHARGER_I2C_REG_CURRENT_1 0x66
#define CHARGER_I2C_REG_CURRENT_2 0x67

// charge controller needs some time to enter I2C mode, at least 500 msec
#define CHARGER_I2C_START_DELAY     600
// From datasheet: "Two short press in 1s: turn off boost output, ..." This delay prevent double-click
#define CHARGER_I2C_WAKE_UP_DELAYS  5000
#define CHARGER_I2C_TIMEOUT         50

#define CHARGER_I2C_DELAYS_DONE     0x01

#define CHARGER_ADC_ION             (11 * 50 / 10)
#define CHARGER_CONTROL_ADC_TIMEOUT 10

#define CHARGER_CONTROL_MAXV_X100   420
#define CHARGER_CONTROL_MINV_X100   310

volatile uint32_t charger_control_enable_i2c_time = 0;
volatile uint8_t charger_adc_voltage_x50 = 0;
uint32_t charger_control_last_wake_up = 0;

bool charger_control_read_adc(t_charger_data & data);

ISR (ADC_vect) {
  uint16_t adch = ADCH - 1;
  if (adch == 0) {
    charger_adc_voltage_x50 = 0;
  } else {
    charger_adc_voltage_x50 = ((uint16_t)CHARGER_ADC_ION * 255) / adch;
  }
}

uint8_t charger_read_byte(uint8_t address) {
  Wire.beginTransmission(CHARGER_I2C_ADDR);
  Wire.write(address);
  Wire.endTransmission(false);
  Wire.requestFrom(CHARGER_I2C_ADDR, 1, false);

  uint32_t now = clock_millis();
  while (!Wire.available()) {
    if (clock_is_elapsed(now, CHARGER_I2C_TIMEOUT)) {
      Wire.endTransmission();
      return 0;
    }
  }
  
  uint8_t v = Wire.read();
  Wire.endTransmission();
  return v;
}

void charger_control_init() {
  pinMode(CHARGER_INT_PIN, INPUT);

  if (digitalRead(CHARGER_INT_PIN) == HIGH) {
    charger_control_enable_i2c_time = clock_millis();
  }

  charger_control_leave_sleep_mode();

  ADCSRA = 0; // disable ADC
  ADMUX = (0 << REFS1) | (1 << REFS0) | // reference: internal 1.1V
          (1 << ADLAR) | // ADC Left Adjust Result
          (0 << MUX0) | (1 << MUX1)  | (1 << MUX2)  | (1 << MUX3); // input: 1.1V (VBG)
}

void isrcall_charger_control_onusbint() {
  if (digitalRead(CHARGER_INT_PIN) == HIGH) {
    if (charger_control_enable_i2c_time == 0) {
      charger_control_enable_i2c_time = clock_millis(true);
    }

    isrcall_powersave_leave_standby();
  } else {
    charger_control_enable_i2c_time = 0;
  }
}

bool charger_control_is_active() {
  return digitalRead(CHARGER_INT_PIN) == HIGH;
}

void charger_control_on_main_loop() {
  if (charger_control_enable_i2c_time == 0 && 
      digitalRead(CHARGER_INT_PIN) == HIGH) {
    // we awakes after sleep mode, but charger still works
    charger_control_enable_i2c_time = clock_millis();
  }
  
  if (charger_control_enable_i2c_time > 0 && charger_control_enable_i2c_time != CHARGER_I2C_DELAYS_DONE) {
    if (digitalRead(CHARGER_INT_PIN) == LOW) {
      // charger powered-off during init-i2c process
      charger_control_enable_i2c_time = 0;
    } else {
      if (clock_is_elapsed(charger_control_enable_i2c_time, CHARGER_I2C_START_DELAY)) {
          charger_control_enable_i2c_time = CHARGER_I2C_DELAYS_DONE;
      }
    }
  }
}

void charger_control_read_i2c(t_charger_data & data) {
  uint32_t value = charger_read_byte(CHARGER_I2C_REG_VOLTAGE_2) << 8;
  value += charger_read_byte(CHARGER_I2C_REG_VOLTAGE_1);
  if (value == 0xFFFF || value == 0x0000) { // problems with I2C, use ADC
    charger_control_read_adc(data);
    return;
  }

  value = (value * 26855) / 1000000;
  data.bat_voltage_x100 = value + 260;

  value = charger_read_byte(CHARGER_I2C_REG_CURRENT_2) << 8;
  value += charger_read_byte(CHARGER_I2C_REG_CURRENT_1);

  if (value > 0x7FFF) {
    value = 0xFFFF - value;
  }

  data.bat_current_x10 = (value * 127883) / 10000000;
  data.i2c_in_use = true;
}

bool charger_control_get_data(t_charger_data & data) {
  if (digitalRead(CHARGER_INT_PIN) == LOW) {
    if (charger_control_last_wake_up != 0 && 
        !clock_is_elapsed(charger_control_last_wake_up, CHARGER_I2C_WAKE_UP_DELAYS)) {
      // dont spam controller via wake-up commands
      return charger_control_read_adc(data);
    }

    charger_control_last_wake_up = clock_millis();

    for (uint8_t i = 0; i<5; i++) {
      // await some time to make sure charger wakes up
      if (digitalRead(CHARGER_INT_PIN) == HIGH) {
        break;
      }

      clock_delay(10);
    }
    
    return charger_control_read_adc(data);
  }

  if (charger_control_enable_i2c_time > 0 && charger_control_enable_i2c_time != CHARGER_I2C_DELAYS_DONE) {
    // await for a I2C startups
    return charger_control_read_adc(data);
  }

  charger_control_read_i2c(data);

  return true;
}

bool charger_control_read_adc(t_charger_data & data) {
  ADCSRA =  (1 << ADEN) | // enable ADC
            (0 << ADSC) | // dont start now
            (1 << ADIE) | // enable interrupt
            (1 << ADPS2)|(1 << ADPS1)|(0 << ADPS0); // prescaler 64

  uint16_t result_x50 = 0;
  for (uint8_t i = 0; i<64; i++) { // 64 (==2^6) measurements to get average result.
    uint32_t now = clock_millis();
    charger_adc_voltage_x50 = 0xFF;
    ADCSRA |= (1 << ADSC);
    while (charger_adc_voltage_x50 == 0xFF) {
      if (clock_is_elapsed(now, CHARGER_CONTROL_ADC_TIMEOUT)) {
        return false;
      }
    }
    result_x50 += charger_adc_voltage_x50;
  }

  ADCSRA = 0; // Finish. Disable ADC.

  // >>6 -> div 64 to calc avg(x50), <<2 -> mult 2 to x50 -> x100. total >>5
  data.bat_voltage_x100 = (result_x50 >> 5);
  data.i2c_in_use = false;

  return data.bat_voltage_x100 > 0;
}

void charger_control_enter_sleep_mode() {
  charger_control_enable_i2c_time = 0;
  ADCSRA = 0;
}

void charger_control_leave_sleep_mode() {
  Wire.begin();
  Wire.setClock(200000);
}

uint8_t charger_control_get_voltage_pc() {
  t_charger_data data;
  memset(&data, 0, sizeof(data));
  if (charger_control_read_adc(data)) {
    if (data.bat_voltage_x100 >= CHARGER_CONTROL_MAXV_X100) {
      return 100;
    } else if (data.bat_voltage_x100 <= CHARGER_CONTROL_MINV_X100) {
      return 0;
    }

    return ((data.bat_voltage_x100 - (uint16_t)CHARGER_CONTROL_MINV_X100) * 100) / ((uint16_t)CHARGER_CONTROL_MAXV_X100 - (uint16_t)CHARGER_CONTROL_MINV_X100);
  } else {
    return 0x00;
  }
}

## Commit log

2022-12-23 continue working under firmware and schematics
    [xray.csv, xray.kicad_pcb, xray.kicad_sch]
2022-12-23 fixed display schematics
    [xray.kicad_pcb, xray.kicad_sch]
2022-12-26 continue working under schematics and firmware
    [xray.csv, xray.kicad_pcb, xray.kicad_sch]
2022-12-26 added fuse to vbat
    [xray.kicad_pcb, xray.kicad_sch]
2023-01-17 board production started
    [supply-calc.ods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]
2023-04-03 Intermediate commit before re-writing ATMega and IP5328 integration
    [memory-dump-no-ntc.txt, sbt11-ring-buttom.stl, sbt11-ring-cup.stl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]
2023-04-05 Prepare to re-write UI
    [xray.kicad_pcb, xray.kicad_sch]
2023-04-10 Prepare to rewrite display driver - remove fillCircle and fillTriangle method calls
2023-04-10 Prepare to rewrite display driver
2023-04-10 UI rewrited to simplified driver. It's saves 60 bytes RAM and 7.5KB PROGMEM on simulator
2023-04-11 Re-writed driver for ST7735 display
2023-04-11 fixed issue with hardware display
    [config.h, display_spi.cpp, uv_control.cpp]
2023-04-14 prepare to write sleep mode
    [supply-calc.ods]
2023-04-18 UV power stabilized
    [supply-calc.ods, xray.kicad_sch]
2023-05-02 1. added reverrsed W2-PD(IP).v1.0 schematics. 2. minor code changes. 3. added fixme notes on schematics
    [W2-PD(IP).v1.0.kicad_pcb, W2-PD(IP).v1.0.kicad_sch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]
2023-05-13 fixed hardware error
    [xray.kicad_sch]
2023-05-14 Continue working under device - reduced one-impulse signals, fixed some hardware problems
    [sbt11-ring-cup.stl, sbt11-ring.FCStd, xray.kicad_sch]
2023-05-15 Fixed wrong information during startup
    [rad_control.cpp]
2023-05-15 1. Changed one-event sound. Fixed error on settings page with cursor
    [config.h, gui_page_settings.cpp, xray-detector.ino]
2023-05-16 Start working under EXT STB
    [supply-calc.ods, xray.kicad_sch]
2023-05-16 EXT STB
    [supply-calc.ods]
2023-05-16 1. Added auto-sleep function; 2. fixed compiler warnings
    [supply-calc.ods]
2023-05-23 preparing to print box
    [box-buttom-cap-back.stl, box-buttom-cap-front.stl, box-cup.stl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]
2023-05-26 working under box
    [box-upper-cap.stl]
2023-05-26 fix in box 3d model
    [box-buttom-cap-back.stl, box-buttom-cap-front.stl, box-upper-cap.stl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]
2023-06-29 changes in 3D model
    [box-buttom-cap-front.stl, box-cup.stl, box-key.stl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]
2023-08-10 v2 board - fixed errors in v1
    [xray-v2-B_Cu.gbr, xray-v2-B_Mask.gbr, xray-v2-B_Paste.gbr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]
2023-08-10 Display changed 1.8'' -> 2.2''
    [xray-v2.kicad_pcb, xray-v2.kicad_sch]
2023-08-10 Gerber files exported for a new display
    [xray-v2-B_Cu.gbr, xray-v2-B_Mask.gbr, xray-v2-B_Paste.gbr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]
2023-08-14 changed usb-flush schematics
    [xray-v2-B_Cu.gbr, xray-v2-B_Mask.gbr, xray-v2-B_Paste.gbr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]
2023-08-15 Board prepared to order
    [xray-v2-B_Cu.gbr, xray-v2-B_Mask.gbr, xray-v2-B_Paste.gbr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]
2023-11-20 Board v2 ordered. Preparing firmware to work with board-v2
    [xray-v2-B_Cu.gbr, xray-v2-B_Mask.gbr, xray-v2-B_Paste.gbr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]
2023-11-22 prepare to rewrite UI
    [box-v2-display-holder.stl, box-v2-usb-solder-helper.stl, box-v2.FCStd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]
2023-12-23 hardware works, printing box
    [box-v2-cup.stl, box-v2-rad-cap.stl, box-v2-top.stl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]
2023-12-30 remove old 3d models
    [box-buttom-cap-back.stl, box-buttom-cap-front.stl, box-cup.stl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]
2023-12-31 updates in model and firmware
    [box-v2-encoder-cup.stl]
2024-01-01 fix UV generation in powersave mode
2024-01-01 try to fix HIGH VALUE in Current Accumulated Dose field
2024-01-01 fix UI issue - selected item arrow centred over menu element
    [gui_page_settings.cpp]
2024-01-12 change timer impulses source in deep-sleep-mode: use T2 and disable WD to more accuacy time calculation
2026-07-24 schematics v3.6.1
    [xray-v3.6.csv, xray-v3.csv, xray-v3.kicad_pcb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]
2026-07-31 writing fw
    [xray-v3.kicad_pcb, xray-v3.kicad_sch]
2026-08-11 add battery integration
2026-08-12 fixed problem with timer; ui changes
2026-08-21 alert manager - sync both chips, add commands to uart and i2c
